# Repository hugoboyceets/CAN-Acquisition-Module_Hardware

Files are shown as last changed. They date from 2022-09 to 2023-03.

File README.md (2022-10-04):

# CAN-Acquisition-Module_Hardware

It's a data acquisition module that can communicate to a PC (and to other modules) over CANbus. This allows for cheap & rugged hardware, as well as simplified wiring and long transmission distances.

At it's core is a Nuvoton M483 microcontroller (ARM Cortex-M4F). It has 8 thermistor inputs, 4 multipurpose analog inputs, and room to accomodate CO2 and/or humidity sensors over I2C or UART.

It can be configured & monitored over USB (it enumerates as a COM port adapter), and a basic screen is present to facilitate human identification and debugging.

The repository for the firmware can be found [here](https://github.com/hboyce4/CAN-Acquisition-Module_Firmware).
The repository the the PC server program can be found [here](https://github.com/hugoboyceets/CAN-Acquisition-Module_Server).

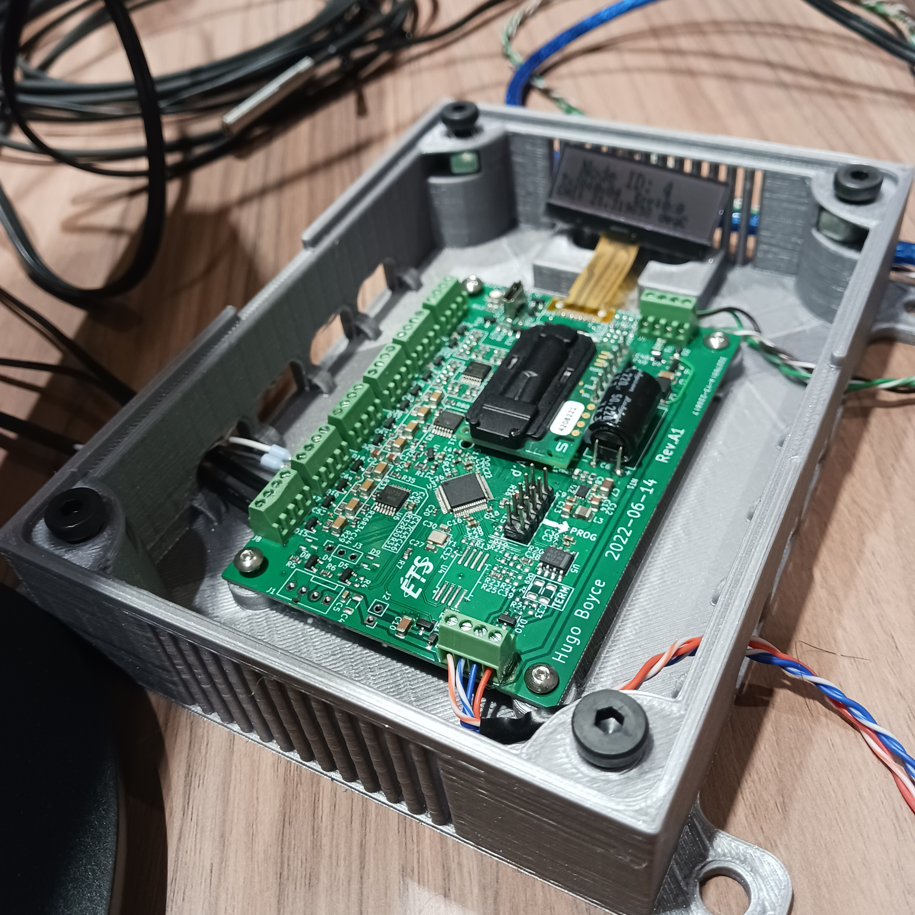
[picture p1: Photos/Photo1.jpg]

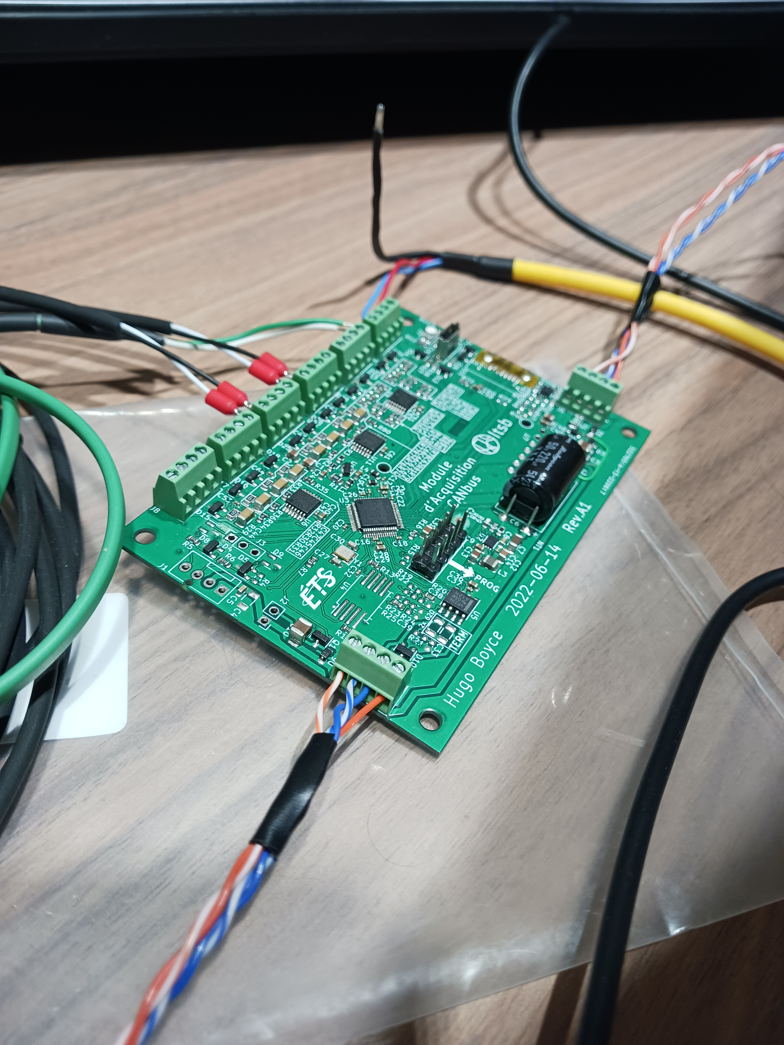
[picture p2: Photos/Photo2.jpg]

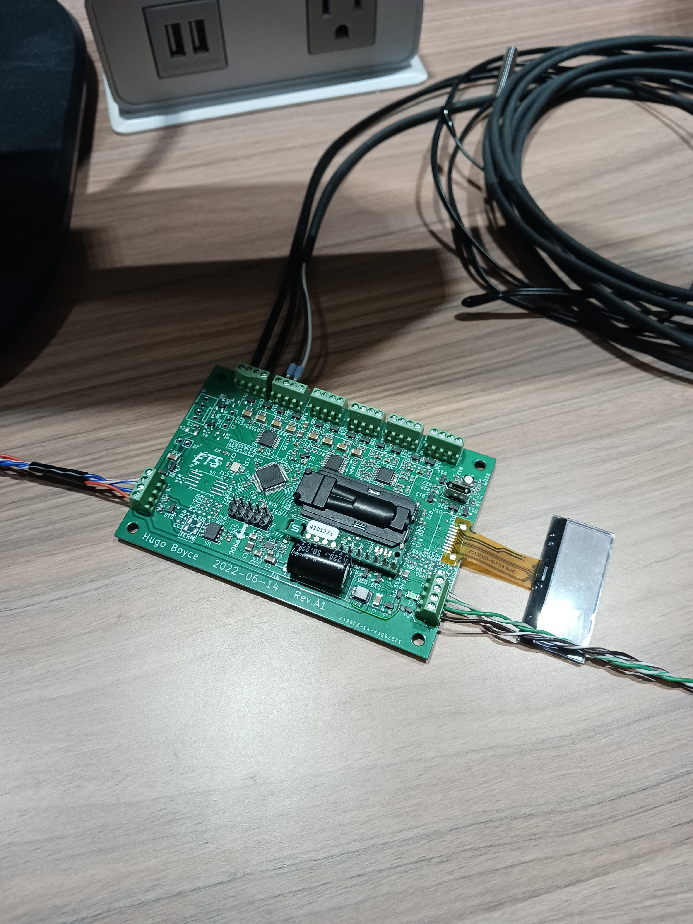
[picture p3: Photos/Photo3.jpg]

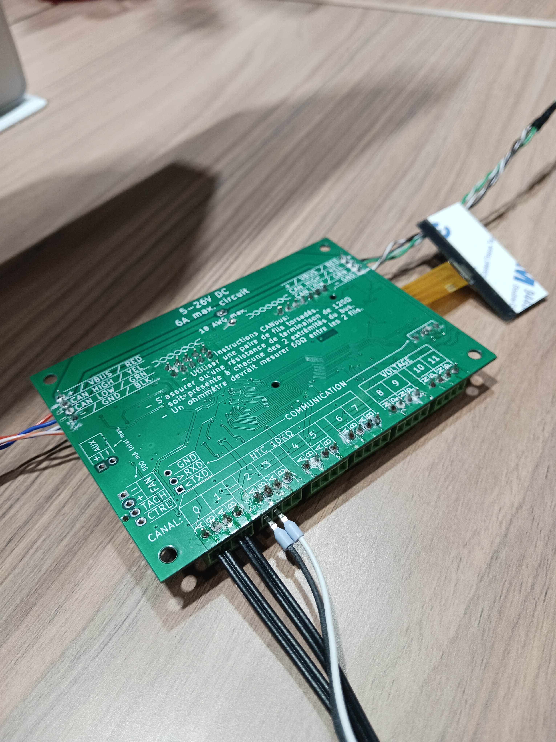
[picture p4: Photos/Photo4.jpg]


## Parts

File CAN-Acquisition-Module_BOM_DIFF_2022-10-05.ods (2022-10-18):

Source: | C:\Users\Hugo Boyce\Documents\Ecole\Maitrise\Projet\PCB\KiCAD\CAN-Acquisition-Module\CAN-Acquisition-Module.kicad_sch
Date: | 2022-10-05 17:15
Tool: | Eeschema (6.0.5)
Generator: | E:\Program Files\KiCad\6.0\bin\scripting\plugins/bom_csv_grouped_by_value_with_fp.py
Component Count: | 210
Ref | Qnty | Stock | Qty needed | Difference | On order | Left | Value | Cmp name | Footprint | Description | Vendor
PCB | 1 | 2
C1, C2, C12, C13, C31, C48, | 6 | 32 | 12 | 20 |  | 20 | 10 uF | C_Small | Capacitor_SMD:C_0805_2012Metric | Unpolarized capacitor, small symbol
C3, C4, C7, C10, C44, C45, C46, C47, C65, C66, C67, C68, | 12 | 1 | 24 | -23 | 25 | 2 | 4.7 uF | C_Small | Capacitor_SMD:C_1206_3216Metric | Unpolarized capacitor, small symbol
C5, C8, | 2 | 44 | 4 | 40 |  | 40 | 100 nF | C_Small | Capacitor_SMD:C_0603_1608Metric | Unpolarized capacitor, small symbol
C6, | 1 | 7 | 2 | 5 |  | 5 | 220 uF | C_Polarized_Small | CAN-Acquisition-Module:CP_Radial_D10.0mm_P5.00mm_Horizontal | Polarized capacitor, small symbol
C9, C15, C19, C23, C24, C29, C36, C40, C49, C51, C55, C56, C57, C58, C59, C61, | 16 | 52 | 32 | 20 |  | 20 | 1 uF | C_Small | Capacitor_SMD:C_0603_1608Metric | Unpolarized capacitor, small symbol
C11, | 1 | 7 | 2 | 5 |  | 5 | 33 pF | C_Small | Capacitor_SMD:C_0603_1608Metric | Unpolarized capacitor, small symbol
C14, C16, C17, C18, C20, C21, C22, C25, C26, C28, C32, C37, C41, C42, C43, C50, C52, C53, C54, C60, C62, C63, C64, | 23 | 33 | 46 | -13 | 50 | 37 | 100 nF | C_Small | Capacitor_SMD:C_0402_1005Metric | Unpolarized capacitor, small symbol
C27, C30, | 2 | 4 | 4 | 0 |  | 0 | 20 pF | C_Small | Capacitor_SMD:C_0603_1608Metric | Unpolarized capacitor, small symbol
C34, C35, | 2 | 4 | 4 | 0 |  | 0 | 47 pF | C_Small | Capacitor_SMD:C_0603_1608Metric | Unpolarized capacitor, small symbol
D1, D2, D6, | 3 | 1 | 6 | -5 | 7 | 2 | CUS05S40 | D | CAN-Acquisition-Module:Toshiba_USC | Diode
D3, D10, | 2 | 4 | 4 | 0 |  | 0 | PESD2CAN | NUP2105L | Package_TO_SOT_SMD:SOT-23 | Dual Line CAN Bus Protector, 24Vrwm
D4, D5, D8, D9, D11, D12, D13, D14, D15, D16, D17, D18, D19, D20, D21, D22, D23, D24, D25, D26, D27, D28, | 22 | 40 | 44 | -4 | 4 | 0 | CM1213A-01SO | CM1213A-01SO | Package_TO_SOT_SMD:SOT-23 | Single Channel ESD Protection Array
D7, | 1 | 1 | 2 | -1 | 2 | 1 | LED_ABRG | LED_ABRG | CAN-Acquisition-Module:LED_RGB_Wuerth-PLCC4_3.2x2.8mm_150141M173100 | RGB LED, anode/blue/red/green
F1, | 1 | 2 | 2 | 0 |  | 0 | 100 mA | Polyfuse_Small | Fuse:Fuse_1206_3216Metric | Resettable fuse, polymeric positive temperature coefficient, small symbol
J4, | 1 | 20 | 2 | 18 |  | 18 | Conn_02x05_Odd_Even | Conn_02x05_Odd_Even | CAN-Acquisition-Module:Nu-Link-Me-v3.0 | Generic connector, double row, 02x05, odd/even pin numbering scheme (row 1 odd numbers, row 2 even numbers), script generated (kicad-library-utils/schlib/autogen/connector/)
J5, J6, J8, J9, J10, J11, J12, J13, | 8 | 1 | 16 | -15 | 15 | 0 | OSTVN04A150 | Screw_Terminal_01x04 | CAN-Acquisition-Module:OSTVN04A150 | Generic screw terminal, single row, 01x04, script generated (kicad-library-utils/schlib/autogen/connector/)
J7, | 1 | 0 | 2 | -2 | 2 | 0 | USB_B_Micro | USB_B_Micro | CAN-Acquisition-Module:GCT-USB3131-30-0230-A | USB Micro Type B connector
L1, L4, L5, L6, | 4 | 88 | 8 | 80 |  | 80 | Ferrite | L_Small | Inductor_SMD:L_0603_1608Metric | Inductor, small symbol
L2, | 1 | 0 | 2 | -2 | 2 | 0 | 470 uH | L_Iron_Small | CAN-Acquisition-Module:Murata_LQH43_1812(4532_Metric) | Inductor with iron core, small symbol
L3, | 1 | 1 | 2 | -1 | 2 | 1 | 4.7 uH | L_Iron_Small | Inductor_SMD:L_1008_2520Metric | Inductor with iron core, small symbol
 |  |  |  |  |  | 0
Q1, | 0 | 1 | 0 | 1 |  | 1 | SI2318A | 2N7002K | Package_TO_SOT_SMD:SOT-23 | 0.38A Id, 60V Vds, N-Channel MOSFET, SOT-23
R1, | 1 | 7 | 2 | 5 |  | 5 | 100R | R_Small_US | Resistor_SMD:R_0805_2012Metric | Resistor, small US symbol
R2, | 1 | 7 | 2 | 5 |  | 5 | 6K8 | R_Small_US | Resistor_SMD:R_0603_1608Metric | Resistor, small US symbol
R3, R9, | 2 | 4 | 4 | 0 |  | 0 | 15K | R_Small_US | Resistor_SMD:R_0603_1608Metric | Resistor, small US symbol
R5, R6, R7, R13, R14, R16, R26, R39, R52, R53, R54, R55, R72, | 13 | 65 | 26 | 39 |  | 39 | 10K | R_Small_US | Resistor_SMD:R_0603_1608Metric | Resistor, small US symbol
R8, R68, R69, R70, R71, | 5 | 86 | 10 | 76 |  | 76 | 47K | R_Small_US | Resistor_SMD:R_0603_1608Metric | Resistor, small US symbol
R10, | 1 | 7 | 2 | 5 |  | 5 | 300R | R_Small_US | Resistor_SMD:R_0603_1608Metric | Resistor, small US symbol
R11, | 1 | 0 | 2 | -2 | 10 | 8 | 220R | R_Small_US | Resistor_SMD:R_0603_1608Metric | Resistor, small US symbol
R12, | 1 | 6 | 2 | 4 |  | 4 | 120R | R_Small_US | Resistor_SMD:R_0603_1608Metric | Resistor, small US symbol
R20, | 1 | 7 | 2 | 5 |  | 5 | 22K | R_Small_US | Resistor_SMD:R_0603_1608Metric | Resistor, small US symbol
R25, R50, R51, R60, R61, R62, R63, | 7 | 79 | 14 | 65 |  | 65 | 1K | R_Small_US | Resistor_SMD:R_0603_1608Metric | Resistor, small US symbol
R27, R28, | 2 | 4 | 4 | 0 |  | 0 | 27R | R_Small_US | Resistor_SMD:R_0603_1608Metric | Resistor, small US symbol
R29, R30, R31, R32, R74, R75, R76, R77, | 8 | 75 | 16 | 59 |  | 59 | 6K2 | R_Small_US | Resistor_SMD:R_0805_2012Metric | Resistor, small US symbol
R33, R34, R35, R36, R78, R79, R80, R81, | 8 | 76 | 16 | 60 |  | 60 | 100R | R_Small_US | Resistor_SMD:R_0603_1608Metric | Resistor, small US symbol
R38, R43, | 2 | 89 | 4 | 85 |  | 85 | 0R | R_Small_US | Resistor_SMD:R_0603_1608Metric | Resistor, small US symbol
R64, R65, R66, R67, | 4 | 0 | 8 | -8 | 10 | 2 | 2K | R_Small_US | Resistor_SMD:R_0603_1608Metric | Resistor, small US symbol
U1, | 1 | 1 | 2 | -1 | 2 | 1 | AZ431LAN | TL431DBZ | Package_TO_SOT_SMD:SOT-23 | Shunt Regulator, SOT-23
U2, | 1 | 7 | 2 | 5 |  | 5 | S-8581AA | S-8581AA | CAN-Acquisition-Module:Ablic_HSTN-8-A | 36 V INPUT, 600 mA SYNCHRONOUS STEP-DOWN SWITCHING REGULATOR
U3, | 1 | 2 | 2 | 0 |  | 0 | M483SGCAE | M483SGCAE2A-CAN-Acquisition-Module | Package_QFP:LQFP-64_7x7mm_P0.4mm
U5, | 1 | 2 | 2 | 0 |  | 0 | SN65HVD234 | SN65HVD234 | Package_SO:SOIC-8_3.9x4.9mm_P1.27mm | CAN Bus Transceiver, 3.3V, 1Mbps, Enable feature, SOIC-8
U6, U11, | 2 | 4 | 4 | 0 |  | 0 | BD12734FVJ-E2 | OPA4196xPW | Package_SO:TSSOP-14_4.4x5mm_P0.65mm | Quad, Low-Power, Low Offset Voltage, Rail-to-Rail Operational Amplifier, TSSOP-14
U7, | 1 | 0 | 2 | -2 | 1 | 0 | SCD30 | SCD30 | CAN-Acquisition-Module:SCD30 | Sensirion IR-based CO2, humidity, and temperature sensor
U8, | 1 | 0 | 2 | -2 | 2 | 0 | SHT35-DIS | SHT35-DIS | CAN-Acquisition-Module:Sensirion_DFN-8-1EP_2.5x2.5mm_P0.5mm_EP1.1x1.7mm | IÃ‚Â²C humidity and temperature sensor, Ã‚Â±1.5%RH, Ã‚Â±0.1Ã‚Â°C, DFN-8
U9, | 1 | 0 | 2 | -2 | 2 | 0 | OPA4317IPWR | OPA4196xPW | Package_SO:TSSOP-14_4.4x5mm_P0.65mm | Quad, Low-Power, Low Offset Voltage, Rail-to-Rail Operational Amplifier, TSSOP-14
U10, | 1 | 0 | 2 | -2 |  | -2 | ERC13232FN-1 | ERC13232FN-1 | CAN-Acquisition-Module:ERC13232FN-1 | EastRising COG Serial 4-line SPI 132x32 Graphic LCD Display No Backlight ST7567A controller
Y1, | 1 | 1 | 2 | -1 | 2 | 1 | 12 MHz | Crystal_GND24_Small | Crystal:Crystal_SMD_3225-4Pin_3.2x2.5mm | Four pin crystal, GND on pins 2 and 4, small symbol

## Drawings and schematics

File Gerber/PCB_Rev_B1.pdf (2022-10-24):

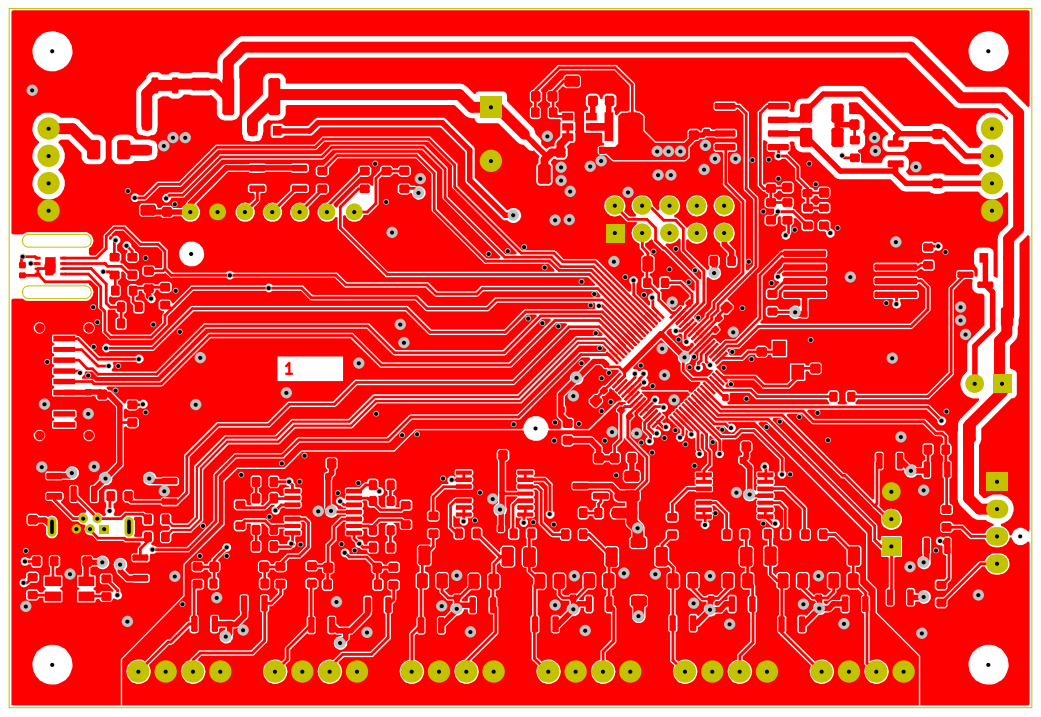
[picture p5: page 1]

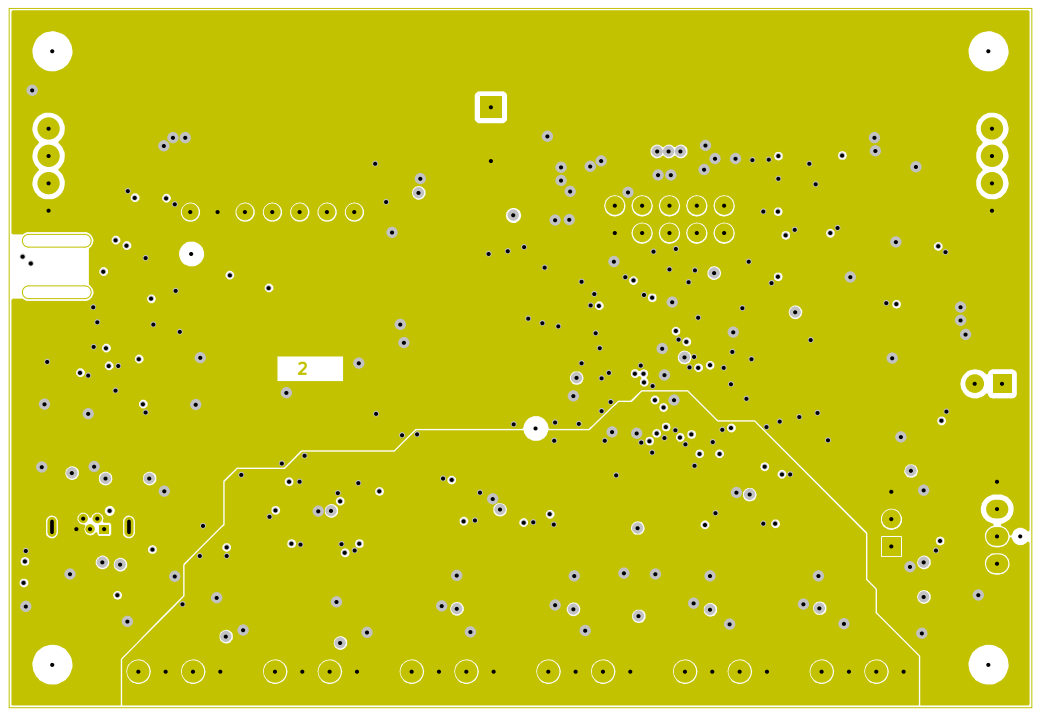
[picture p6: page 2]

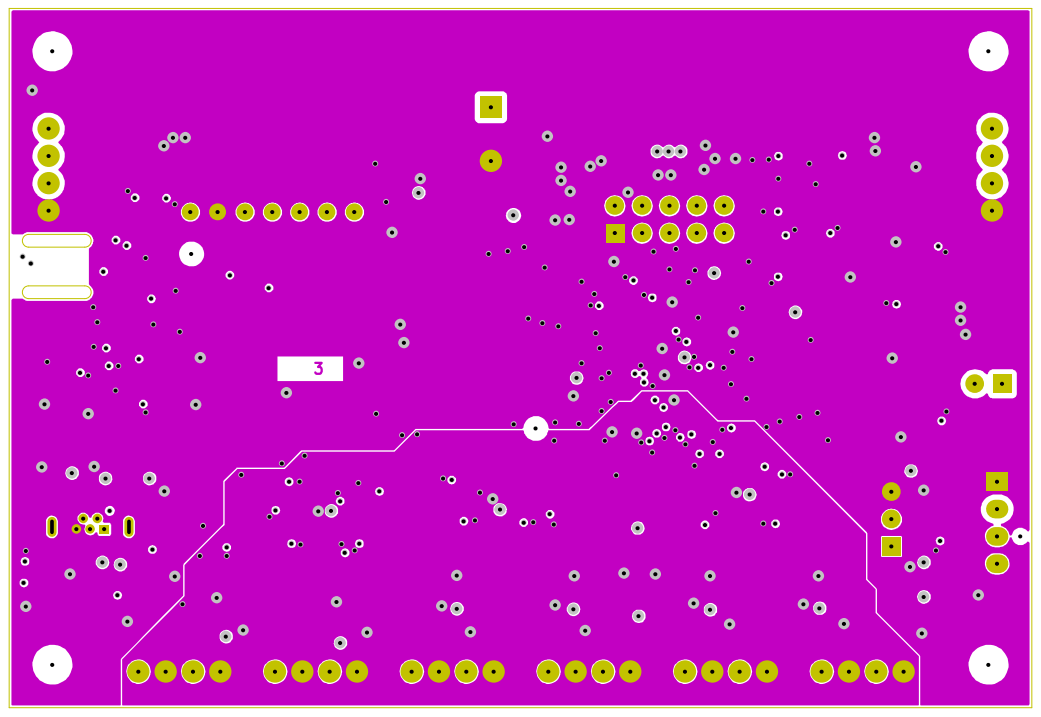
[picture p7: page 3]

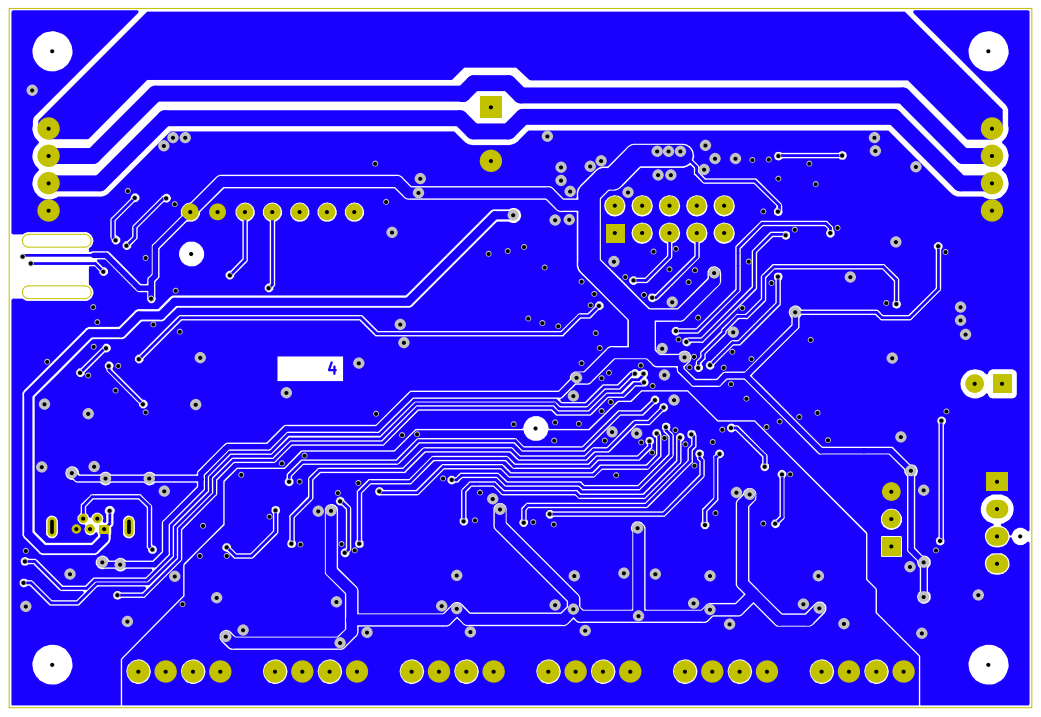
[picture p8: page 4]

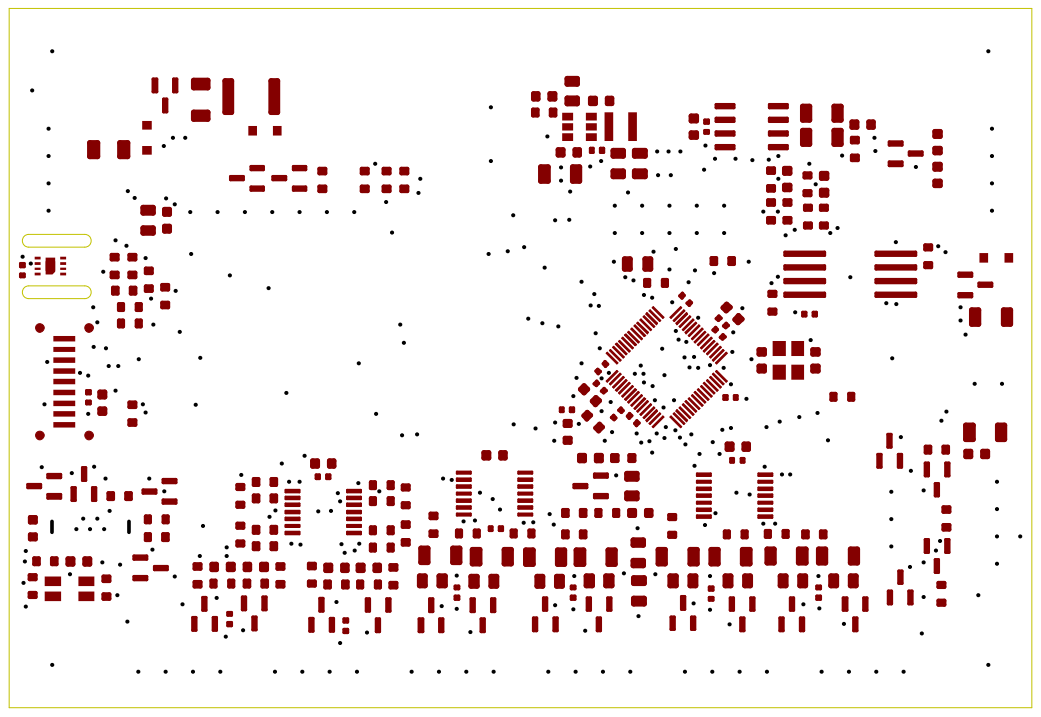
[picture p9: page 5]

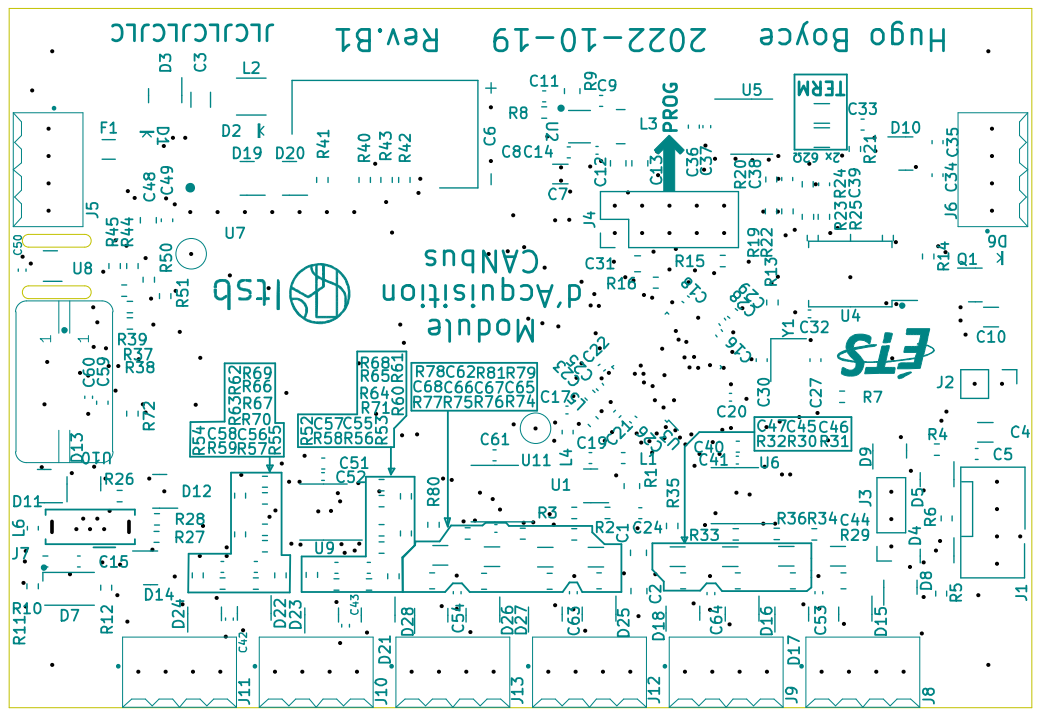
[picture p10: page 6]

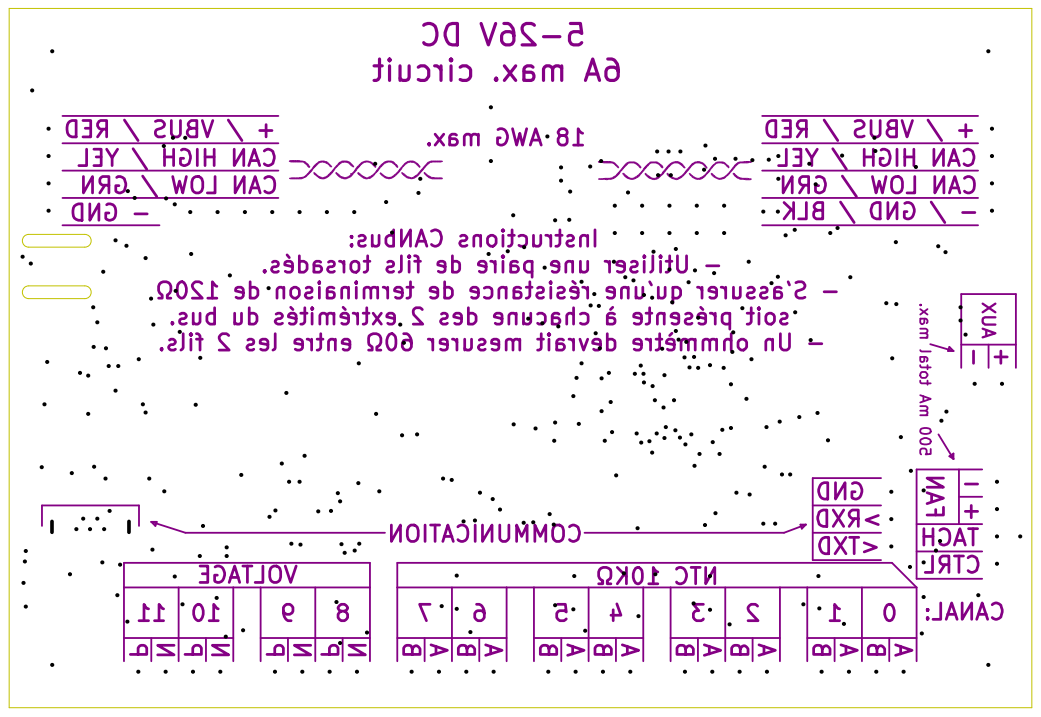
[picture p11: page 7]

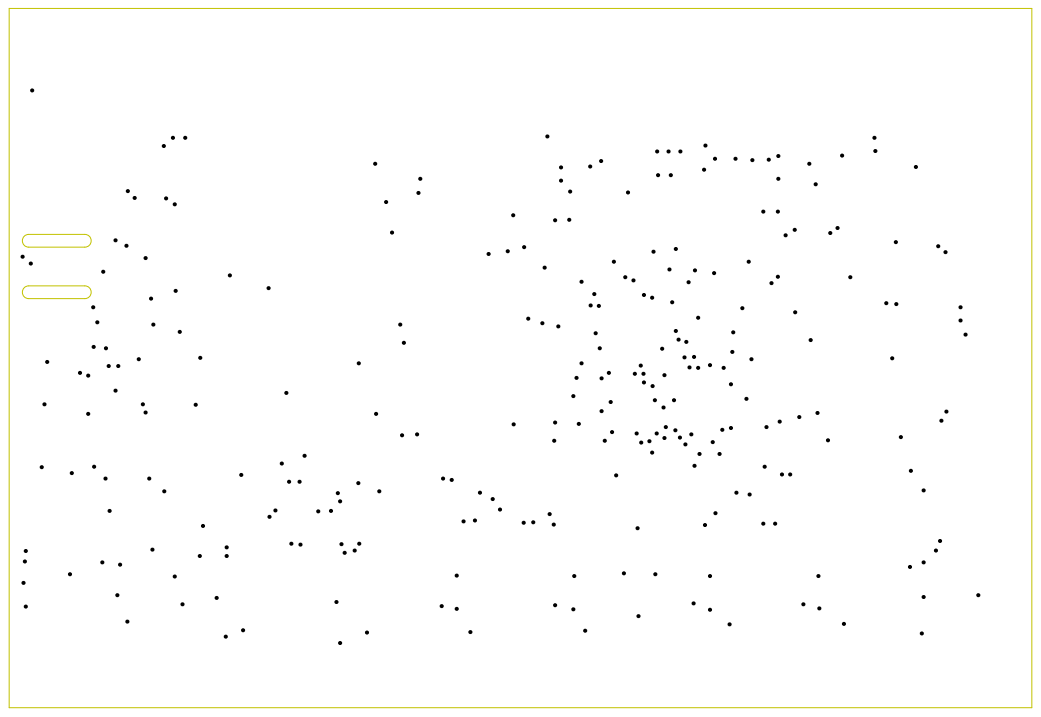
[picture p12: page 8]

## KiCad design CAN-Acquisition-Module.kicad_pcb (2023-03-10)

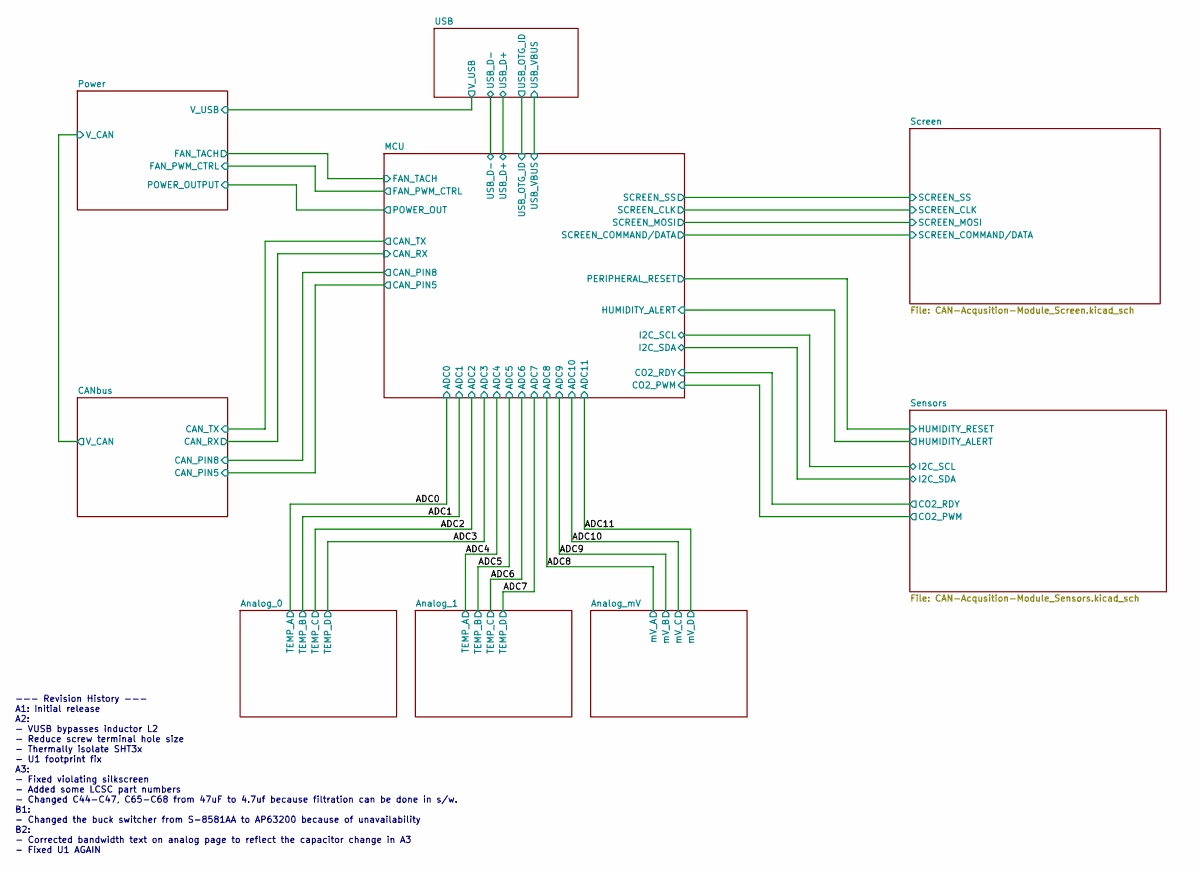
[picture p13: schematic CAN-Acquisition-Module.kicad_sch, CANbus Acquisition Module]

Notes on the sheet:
--- Revision History --- A1: Initial release A2: - VUSB bypasses inductor L2 - Reduce screw terminal hole size - Thermally isolate SHT3x - U1 footprint fix A3: - Fixed violating silkscreen - Added some LCSC part numbers - Changed C44-C47, C65-C68 from 47uF to 4.7uf because filtration can be done in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

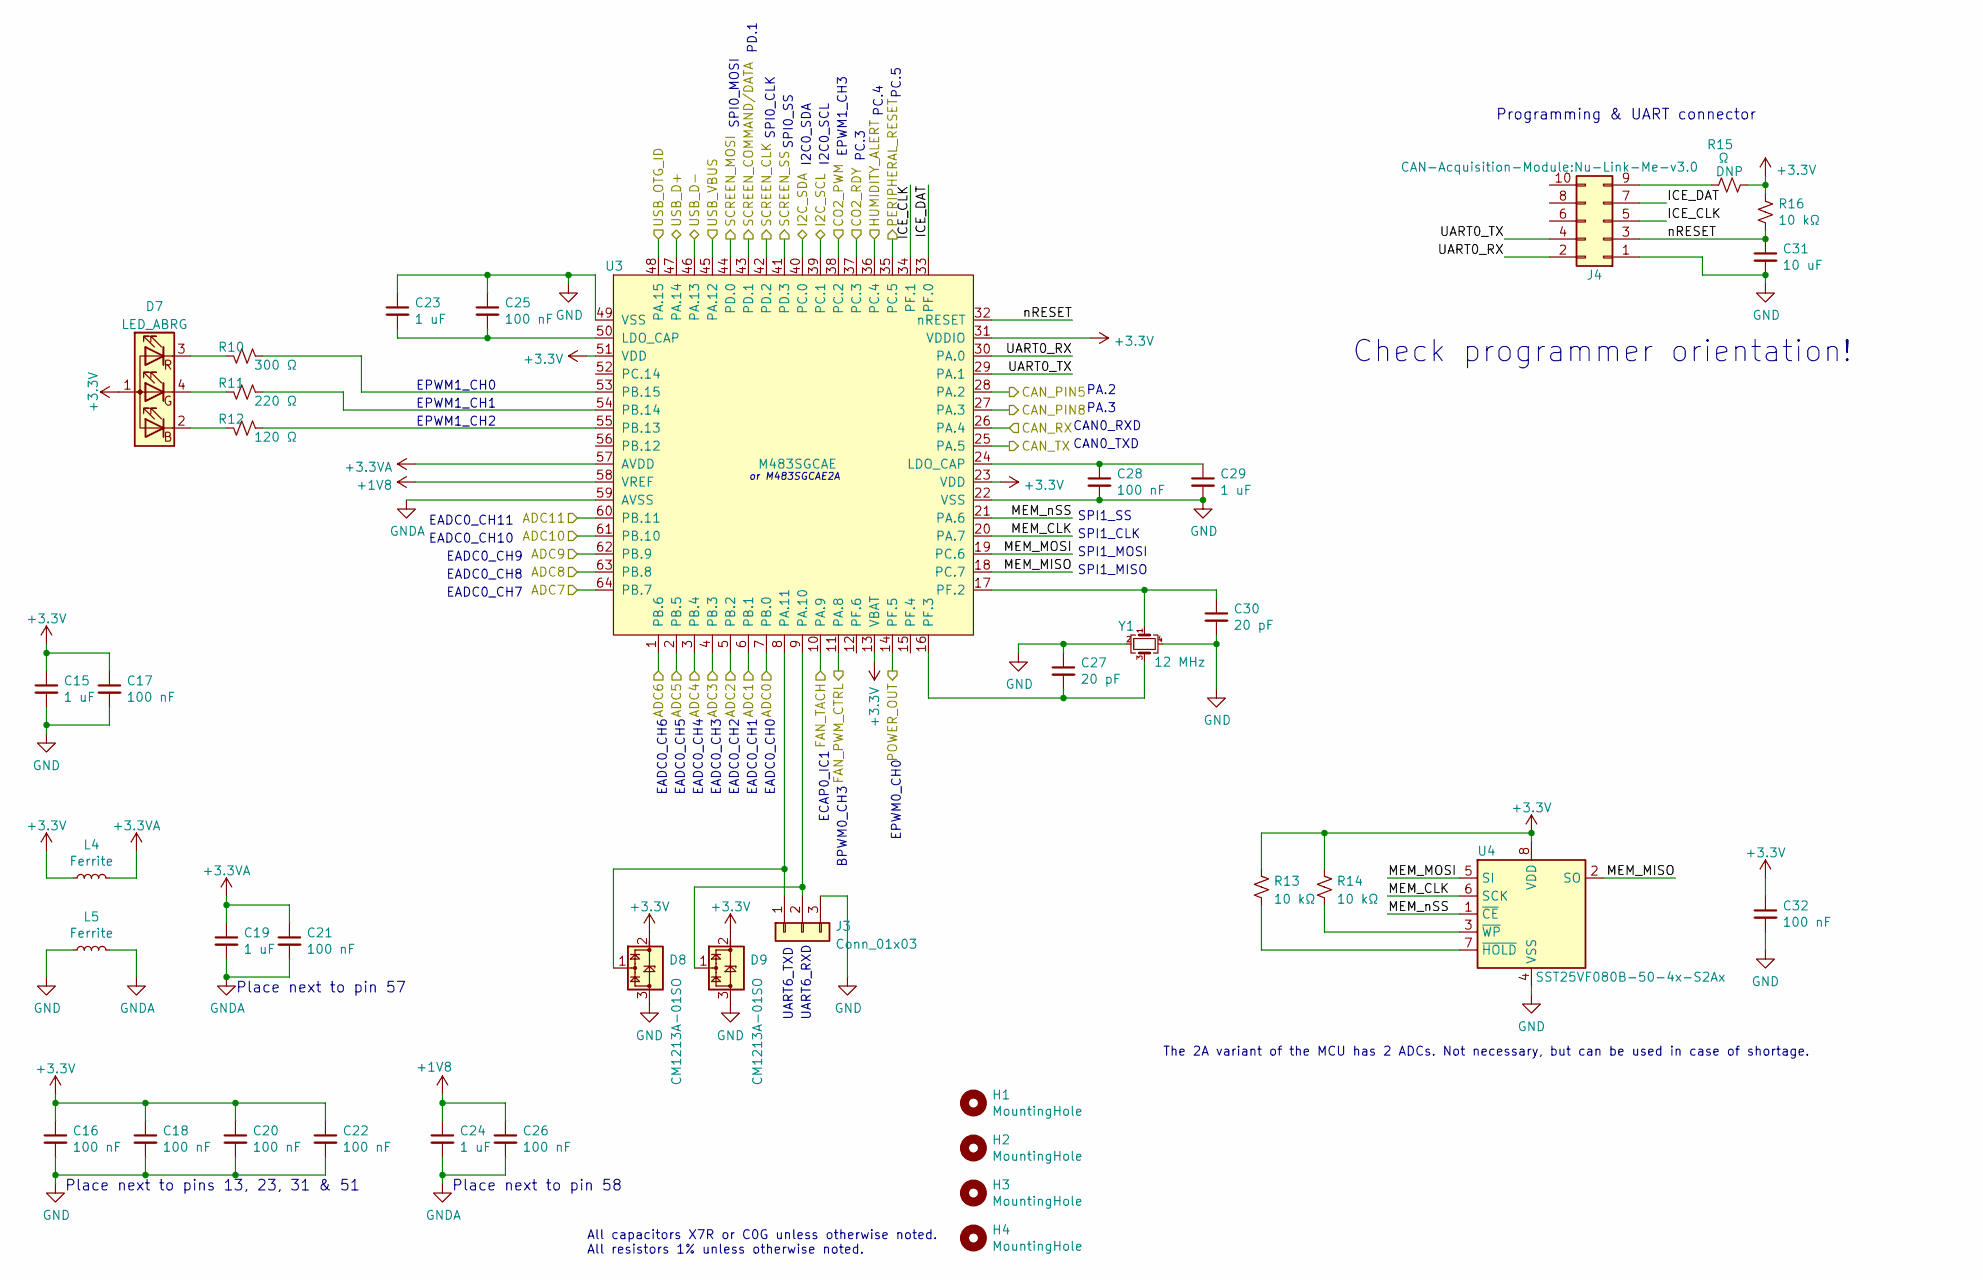
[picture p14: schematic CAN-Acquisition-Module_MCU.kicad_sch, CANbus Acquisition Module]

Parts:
C15, C19, C23, C24, C29: 1 uF; C_0603_1608Metric; Rated Voltage 25V; LCSC P/N C386079
C16, C17, C18, C20, C21, C22, C25, C26, C28, C32: 100 nF; C_0402_1005Metric; Rated Voltage 16V; LCSC P/N C77014
C27, C30: 20 pF; C_0603_1608Metric; LCSC P/N C123543
C31: 10 uF; C_0805_2012Metric; Rated Voltage 6.3V; LCSC P/N C386019
D7: LED_ABRG; LED_RGB_Wuerth-PLCC4_3.2x2.8mm_150141M173100; LCSC P/N C409779
D8, D9: CM1213A-01SO; SOT-23; LCSC P/N C558429
H1, H2, H3, H4: MountingHole; MountingHole_3.2mm_M3; LCSC P/N DNP
J3: Conn_01x03; PinSocket_1x03_P2.54mm_Vertical; LCSC P/N DNP
J4: Conn_02x05_Odd_Even; Nu-Link-Me-v3.0; LCSC P/N C124387
L4, L5: Ferrite; L_0603_1608Metric; LCSC P/N C96995
R10: 300 Ω; R_0603_1608Metric; Tolerance 1%; LCSC P/N C114617
R11: 220 Ω; R_0603_1608Metric; Tolerance 1%; LCSC P/N C22962
R12: 120 Ω; R_0603_1608Metric; Tolerance 1%; LCSC P/N C22787
R13, R14, R16: 10 kΩ; R_0603_1608Metric; Tolerance 1%; LCSC P/N C98220
R15: Ω; R_0603_1608Metric; LCSC P/N DNP
U3: M483SGCAE; LQFP-64_7x7mm_P0.4mm; LCSC P/N C3231235
U4: SST25VF080B-50-4x-S2Ax; SOIC-8_P1.27mm_Multi; LCSC P/N DNP
Y1: 12 MHz; Crystal_SMD_3225-4Pin_3.2x2.5mm; LCSC P/N C91749

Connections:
+1V8: C24.1, C26.1, U3.58 (VREF); also elsewhere on the board
+3.3VA: C19.1, C21.1, L4.2, U3.57 (AVDD); also elsewhere on the board
+3V3: C15.1, C16.1, C17.1, C18.1, C20.1, C22.1, C32.1, D7.1 (A), D8.2 (VP), D9.2 (VP), L4.1, R13.1, R14.1, R15.2, R16.1, U3.13 (VBAT), U3.23 (VDD), U3.31 (VDDIO), U3.51 (VDD), U4.8 (VDD); also elsewhere on the board
/ADC0: U3.7 (PB.0); also elsewhere on the board
/ADC1: U3.6 (PB.1); also elsewhere on the board
/ADC2: U3.5 (PB.2); also elsewhere on the board
/ADC3: U3.4 (PB.3); also elsewhere on the board
/ADC4: U3.3 (PB.4); also elsewhere on the board
/ADC5: U3.2 (PB.5); also elsewhere on the board
/ADC6: U3.1 (PB.6); also elsewhere on the board
/ADC7: U3.64 (PB.7); also elsewhere on the board
/ADC8: U3.63 (PB.8); also elsewhere on the board
/ADC9: U3.62 (PB.9); also elsewhere on the board
/ADC10: U3.61 (PB.10); also elsewhere on the board
/ADC11: U3.60 (PB.11); also elsewhere on the board
/CANbus/CAN_PIN5: U3.28 (PA.2); also elsewhere on the board
/CANbus/CAN_PIN8: U3.27 (PA.3); also elsewhere on the board
/CANbus/CAN_RX: U3.26 (PA.4); also elsewhere on the board
/CANbus/CAN_TX: U3.25 (PA.5); also elsewhere on the board
/MCU/CO2_PWM: U3.38 (PC.2); also elsewhere on the board
/MCU/CO2_RDY: U3.37 (PC.3); also elsewhere on the board
/MCU/FAN_PWM_CTRL: U3.11 (PA.8); also elsewhere on the board
/MCU/FAN_TACH: U3.10 (PA.9); also elsewhere on the board
/MCU/HUMIDITY_ALERT: U3.36 (PC.4); also elsewhere on the board
/MCU/I2C_SCL: U3.39 (PC.1); also elsewhere on the board
/MCU/I2C_SDA: U3.40 (PC.0); also elsewhere on the board
/MCU/ICE_CLK: J4.5, U3.34 (PF.1)
/MCU/ICE_DAT: J4.7, U3.33 (PF.0)
/MCU/MEM_CLK: U3.20 (PA.7), U4.6 (SCK)
/MCU/MEM_MISO: U3.18 (PC.7), U4.2 (SO)
/MCU/MEM_MOSI: U3.19 (PC.6), U4.5 (SI)
/MCU/MEM_nSS: U3.21 (PA.6), U4.1 (~CE)
/MCU/PERIPHERAL_RESET: U3.35 (PC.5); also elsewhere on the board
/MCU/POWER_OUT: U3.14 (PF.5); also elsewhere on the board
/MCU/SCREEN_CLK: U3.42 (PD.2); also elsewhere on the board
/MCU/SCREEN_COMMAND/DATA: U3.43 (PD.1); also elsewhere on the board
/MCU/SCREEN_MOSI: U3.44 (PD.0); also elsewhere on the board
/MCU/SCREEN_SS: U3.41 (PD.3); also elsewhere on the board
/MCU/UART0_RX: J4.2, U3.30 (PA.0)
/MCU/UART0_TX: J4.4, U3.29 (PA.1)
/MCU/USB_D+: U3.47 (PA.14); also elsewhere on the board
/MCU/USB_D-: U3.46 (PA.13); also elsewhere on the board
/MCU/USB_OTG_ID: U3.48 (PA.15); also elsewhere on the board
/MCU/USB_VBUS: U3.45 (PA.12); also elsewhere on the board
/MCU/nRESET: C31.1, J4.3, R16.2, U3.32 (nRESET)
GND: C15.2, C16.2, C17.2, C18.2, C20.2, C22.2, C23.1, C25.1, C27.1, C28.2, C29.2, C30.2, C31.2, C32.2, D8.3 (VN), D9.3 (VN), J3.3, J4.1, L5.1, U3.22 (VSS), U3.49 (VSS), U4.4 (VSS), Y1.2, Y1.4; also elsewhere on the board
GNDA: C19.2, C21.2, C24.2, C26.2, L5.2, U3.59 (AVSS); also elsewhere on the board
unnamed: C23.2, C25.2, U3.50 (LDO_CAP)
unnamed: C27.2, U3.16 (PF.3), Y1.3
unnamed: C28.1, C29.1, U3.24 (LDO_CAP)
unnamed: C30.1, U3.17 (PF.2), Y1.1
unnamed: D7.2 (BK), R12.2
unnamed: D7.3 (RK), R10.2
unnamed: D7.4 (GK), R11.2
unnamed: D8.1 (CH1), J3.1, U3.8 (PA.11)
unnamed: D9.1 (CH1), J3.2, U3.9 (PA.10)
unnamed: J4.9, R15.1
unnamed: R10.1, U3.53 (PB.15)
unnamed: R11.1, U3.54 (PB.14)
unnamed: R12.1, U3.55 (PB.13)
unnamed: R13.2, U4.7 (~HOLD)
unnamed: R14.2, U4.3 (~WP)

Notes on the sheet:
PD.1
I2C0_SDA
SPI1_CLK
Programming & UART connector
PA.3
EADC0_CH9
EPWM1_CH3
EADC0_CH5
Place next to pins 13, 23, 31 & 51
EADC0_CH10
SPI0_SS
The 2A variant of the MCU has 2 ADCs. Not necessary, but can be used in case of shortage.
EPWM1_CH0
PC.5
PC.3
EADC0_CH6
ECAP0_IC1
CAN0_RXD
CAN0_TXD
Place next to pin 58
SPI0_MOSI
EADC0_CH0
Check programmer orientation!
UART6_RXD
PC.4
EPWM1_CH1
UART6_TXD
All capacitors X7R or C0G unless otherwise noted. All resistors 1% unless otherwise noted.
Place next to pin 57
EPWM0_CH0
SPI1_MISO
EADC0_CH7
or M483SGCAE2A
BPWM0_CH3
EADC0_CH8
EADC0_CH1
EADC0_CH2
EPWM1_CH2
EADC0_CH4
SPI0_CLK

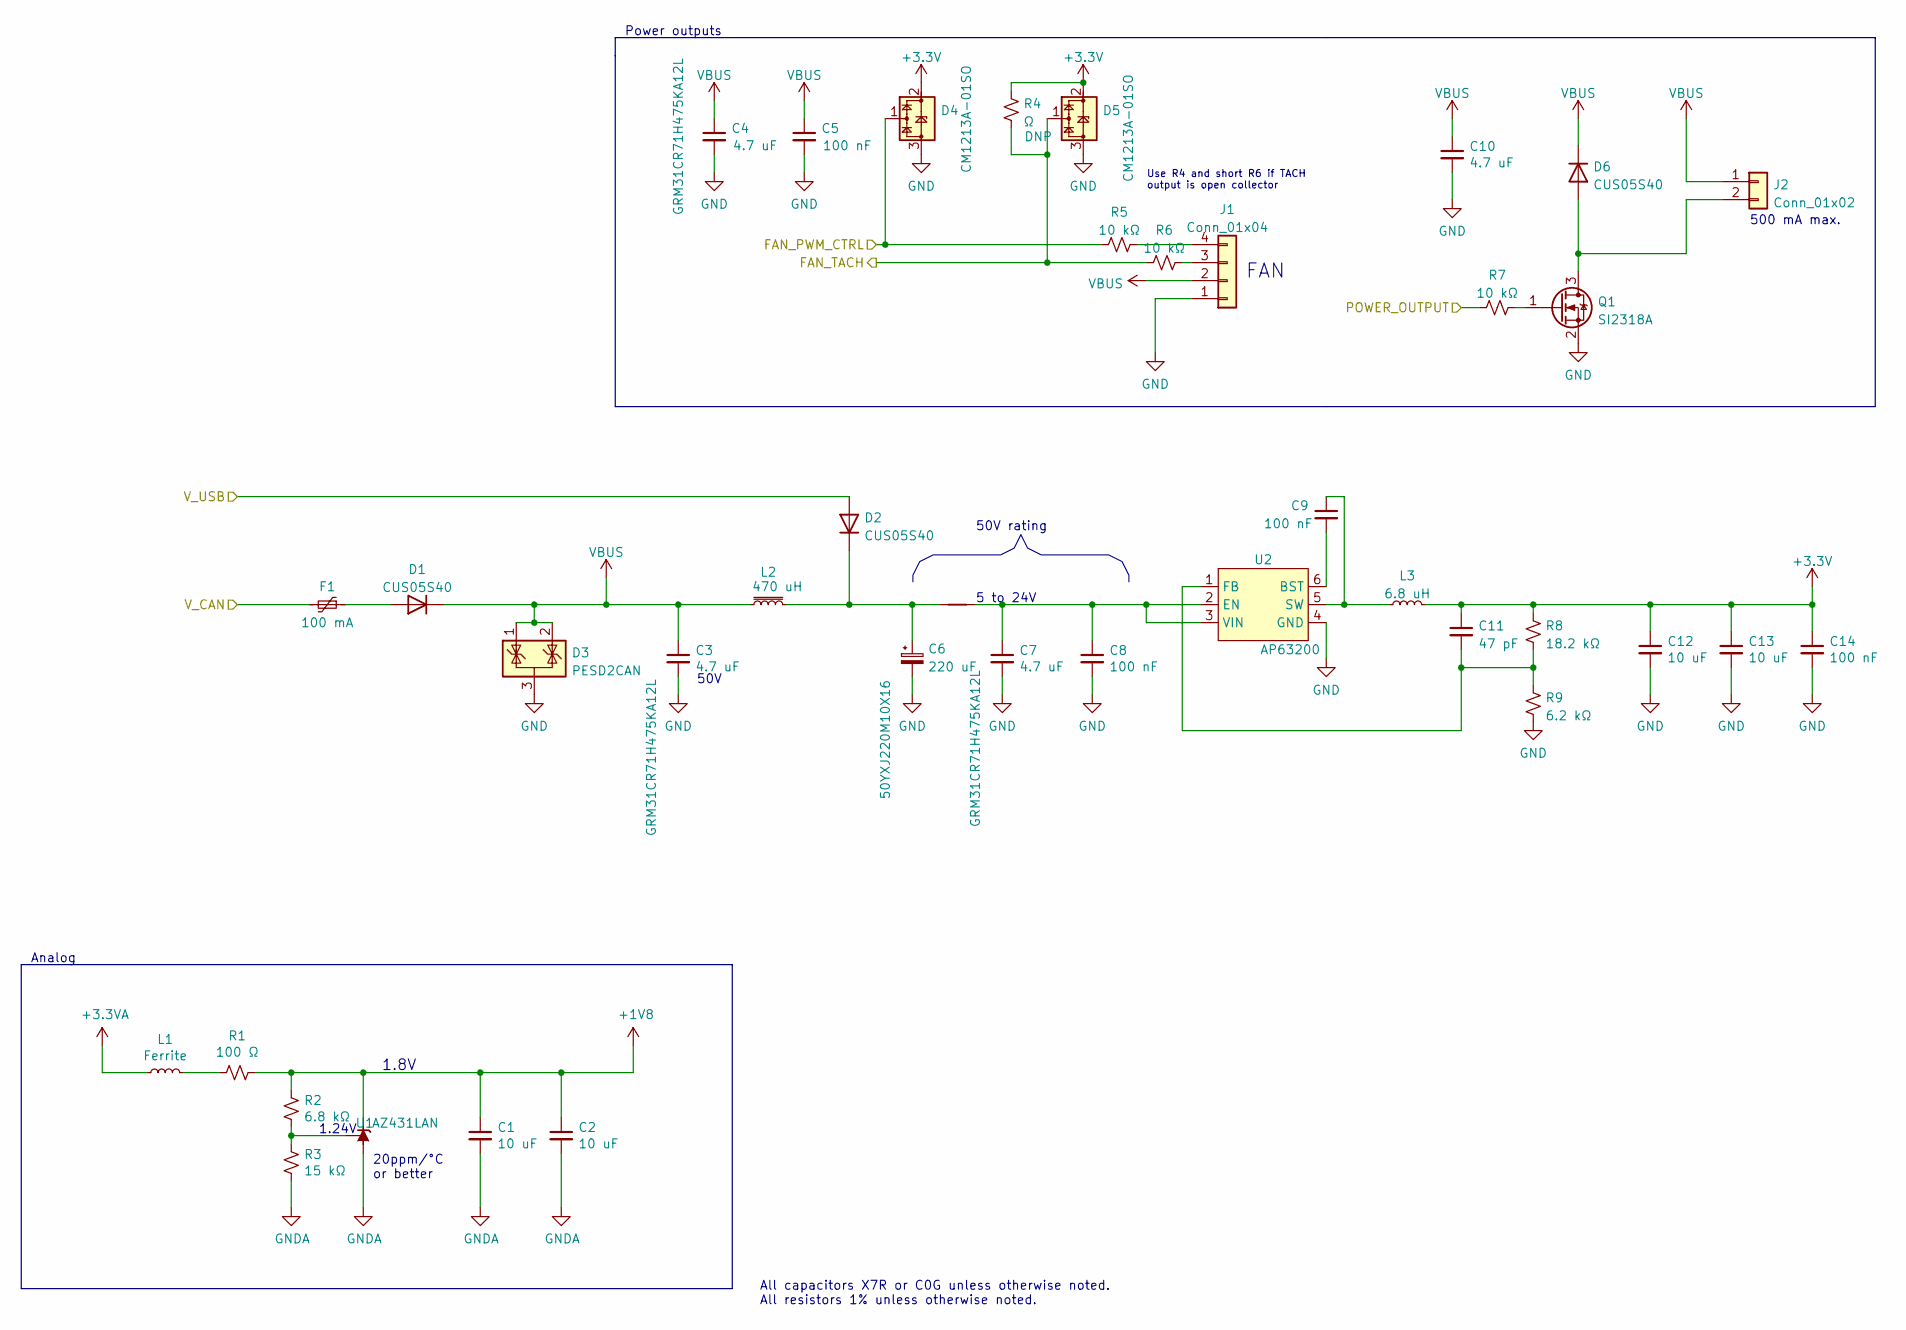
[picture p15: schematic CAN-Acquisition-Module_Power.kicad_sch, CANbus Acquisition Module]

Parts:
C1, C2, C12, C13: 10 uF; C_0805_2012Metric; Rated Voltage 6.3V; LCSC P/N C386019
C3, C4, C7, C10: 4.7 uF; C_1206_3216Metric; Rated Voltage 50V; LCSC P/N C92853
C5, C8, C9: 100 nF; C_0603_1608Metric; Rated Voltage 50V; LCSC P/N C314282
C6: 220 uF; CP_Radial_D10.0mm_P5.00mm_Horizontal; Rated Voltage 50V; LCSC P/N DNP
C11: 47 pF; C_0603_1608Metric; LCSC P/N C126580
C14: 100 nF; C_0402_1005Metric; Rated Voltage 16V; LCSC P/N C77014
D1, D2, D6: CUS05S40; Toshiba_USC; LCSC P/N C2762696
D3: PESD2CAN; SOT-23; LCSC P/N C284078
D4, D5: CM1213A-01SO; SOT-23; LCSC P/N C558429
F1: 100 mA; Fuse_1206_3216Metric; LCSC P/N C70065
J1: Conn_01x04; FanPinHeader_1x04_P2.54mm_Vertical; LCSC P/N DNP
J2: Conn_01x02; PinHeader_1x02_P2.54mm_Vertical; LCSC P/N DNP
L1: Ferrite; L_0603_1608Metric; LCSC P/N C96995
L2: 470 uH; Murata_LQH43_1812(4532_Metric); LCSC P/N C394141
L3: 6.8 uH; Murata_LQH3_1212(3030_Metric); LCSC P/N C703775
NT1: NetTie_2; Net_Tie_small; LCSC P/N DNP
Q1: SI2318A; SOT-23; LCSC P/N DNP
R1: 100 Ω; R_0805_2012Metric; Tolerance 5%; LCSC P/N C17408
R2: 6.8 kΩ; R_0603_1608Metric; Tolerance 0.1%; LCSC P/N C55912
R3: 15 kΩ; R_0603_1608Metric; Tolerance 0.1%; LCSC P/N C60590
R4: Ω; R_0603_1608Metric; LCSC P/N DNP
R5, R6, R7: 10 kΩ; R_0603_1608Metric; Tolerance 1%; LCSC P/N C98220
R8: 18.2 kΩ; R_0603_1608Metric; Tolerance 1%; LCSC P/N C22892
R9: 6.2 kΩ; R_0805_2012Metric; Tolerance 0.1%; LCSC P/N C351551
U1: AZ431LAN; SOT-23; LCSC P/N C460576
U2: AP63200; Diodes-Inc_TSOT26; LCSC P/N C2071868

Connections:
+1V8: C1.1, C2.1, R1.1, R2.1, U1.2 (K); also elsewhere on the board
+3.3VA: L1.1; also elsewhere on the board
+3V3: C11.1, C12.1, C13.1, C14.1, D4.2 (VP), D5.2 (VP), L3.2, R4.2, R8.1; also elsewhere on the board
/CANbus/V+/RED: F1.2; also elsewhere on the board
/MCU/FAN_PWM_CTRL: D4.1 (CH1), R5.1; also elsewhere on the board
/MCU/FAN_TACH: D5.1 (CH1), R4.1, R6.1; also elsewhere on the board
/MCU/POWER_OUT: R7.1; also elsewhere on the board
/Power/V_USB: D2.2 (A); also elsewhere on the board
GND: C3.2, C4.2, C5.2, C6.2, C7.2, C8.2, C10.2, C12.2, C13.2, C14.2, D3.3 (A), D4.3 (VN), D5.3 (VN), J1.1, Q1.2 (S), R9.2, U2.4 (GND); also elsewhere on the board
GNDA: C1.2, C2.2, R3.2, U1.3 (A); also elsewhere on the board
unnamed: C6.1, D2.1 (K), L2.2, NT1.1
unnamed: C7.1, C8.1, NT1.2, U2.2 (EN), U2.3 (VIN)
unnamed: C9.1, L3.1, U2.5 (SW)
unnamed: C9.2, U2.6 (BST)
unnamed: C11.2, R8.2, R9.1, U2.1 (FB)
unnamed: D1.2 (A), F1.1
unnamed: D6.2 (A), J2.2, Q1.3 (D)
unnamed: J1.3, R6.2
unnamed: J1.4, R5.2
unnamed: L1.2, R1.2
unnamed: Q1.1 (G), R7.2
unnamed: R2.2, R3.1, U1.1 (REF)
VBUS: C3.1, C4.1, C5.1, C10.1, D1.1 (K), D3.1 (K), D3.2 (K), D6.1 (K), J1.2, J2.1, L2.1

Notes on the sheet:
50V
5 to 24V
1.8V
FAN
Power outputs
Analog
All capacitors X7R or C0G unless otherwise noted. All resistors 1% unless otherwise noted.
Use R4 and short R6 if TACH output is open collector
1.24V
50V rating
500 mA max.
20ppm/°C or better

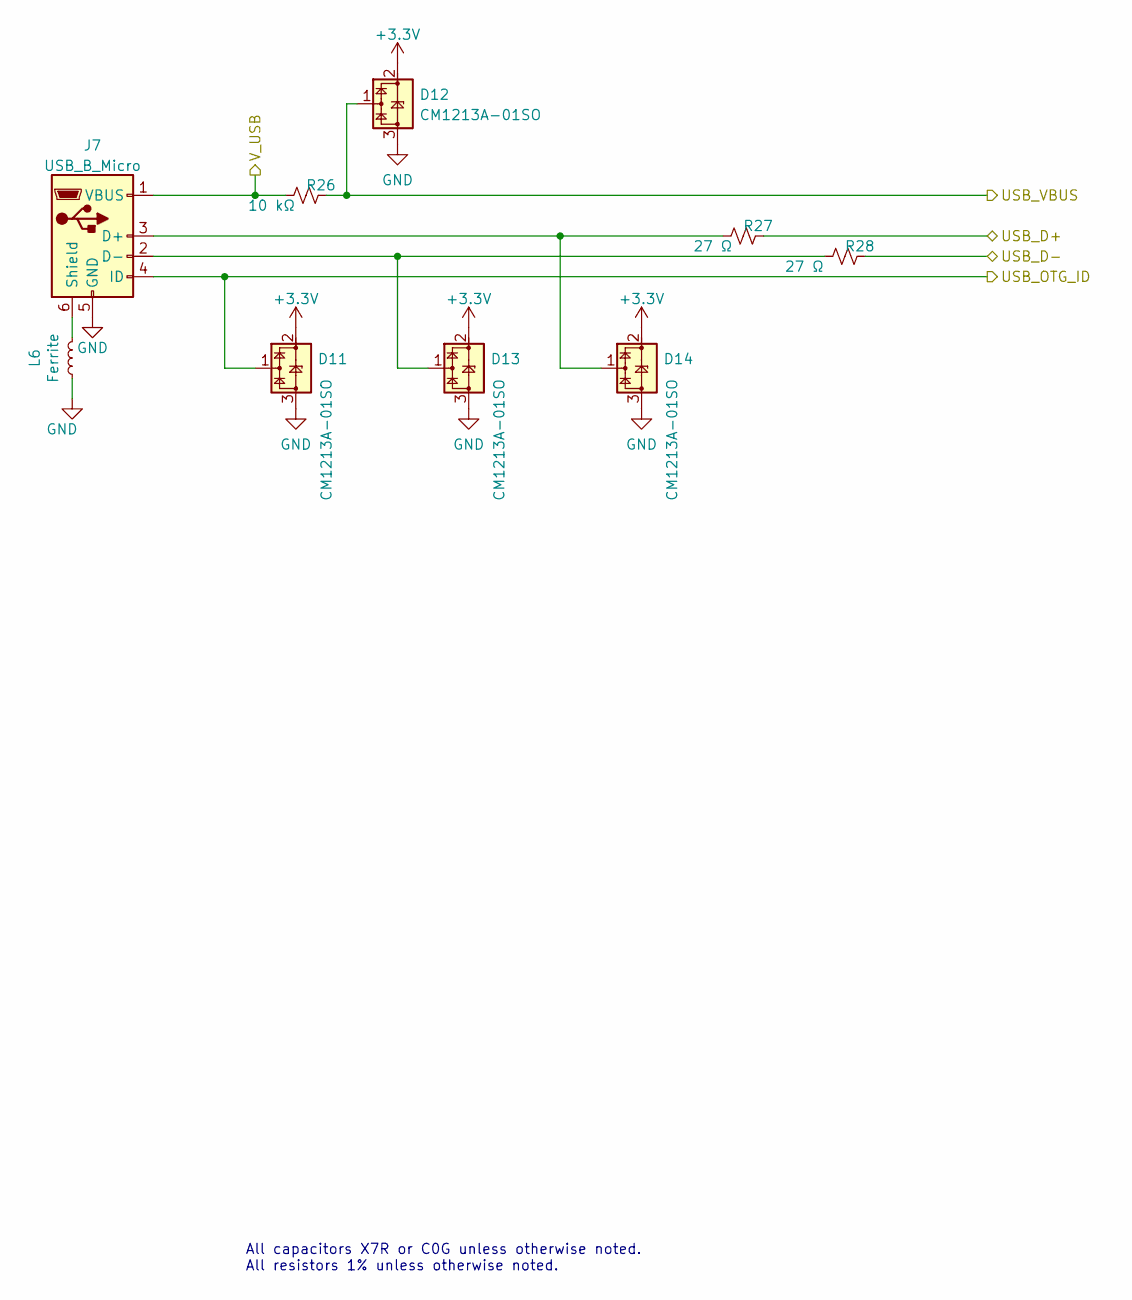
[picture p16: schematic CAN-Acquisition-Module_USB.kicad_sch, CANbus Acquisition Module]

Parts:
D11, D12, D13, D14: CM1213A-01SO; SOT-23; LCSC P/N C558429
J7: USB_B_Micro; GCT-USB3131-30-0230-A; LCSC P/N C920231
L6: Ferrite; L_0603_1608Metric; LCSC P/N C96995
R26: 10 kΩ; R_0603_1608Metric; Tolerance 1%; LCSC P/N C98220
R27, R28: 27 Ω; R_0603_1608Metric; Tolerance 1%; LCSC P/N C25190

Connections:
+3V3: D11.2 (VP), D12.2 (VP), D13.2 (VP), D14.2 (VP); also elsewhere on the board
/MCU/USB_D+: R27.2; also elsewhere on the board
/MCU/USB_D-: R28.2; also elsewhere on the board
/MCU/USB_OTG_ID: D11.1 (CH1), J7.4 (ID); also elsewhere on the board
/MCU/USB_VBUS: D12.1 (CH1), R26.2; also elsewhere on the board
/Power/V_USB: J7.1 (VBUS), R26.1; also elsewhere on the board
GND: D11.3 (VN), D12.3 (VN), D13.3 (VN), D14.3 (VN), J7.5 (GND), L6.1; also elsewhere on the board
unnamed: D13.1 (CH1), J7.2 (D-), R28.1
unnamed: D14.1 (CH1), J7.3 (D+), R27.1
unnamed: J7.6 (Shield), L6.2

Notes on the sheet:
All capacitors X7R or C0G unless otherwise noted. All resistors 1% unless otherwise noted.

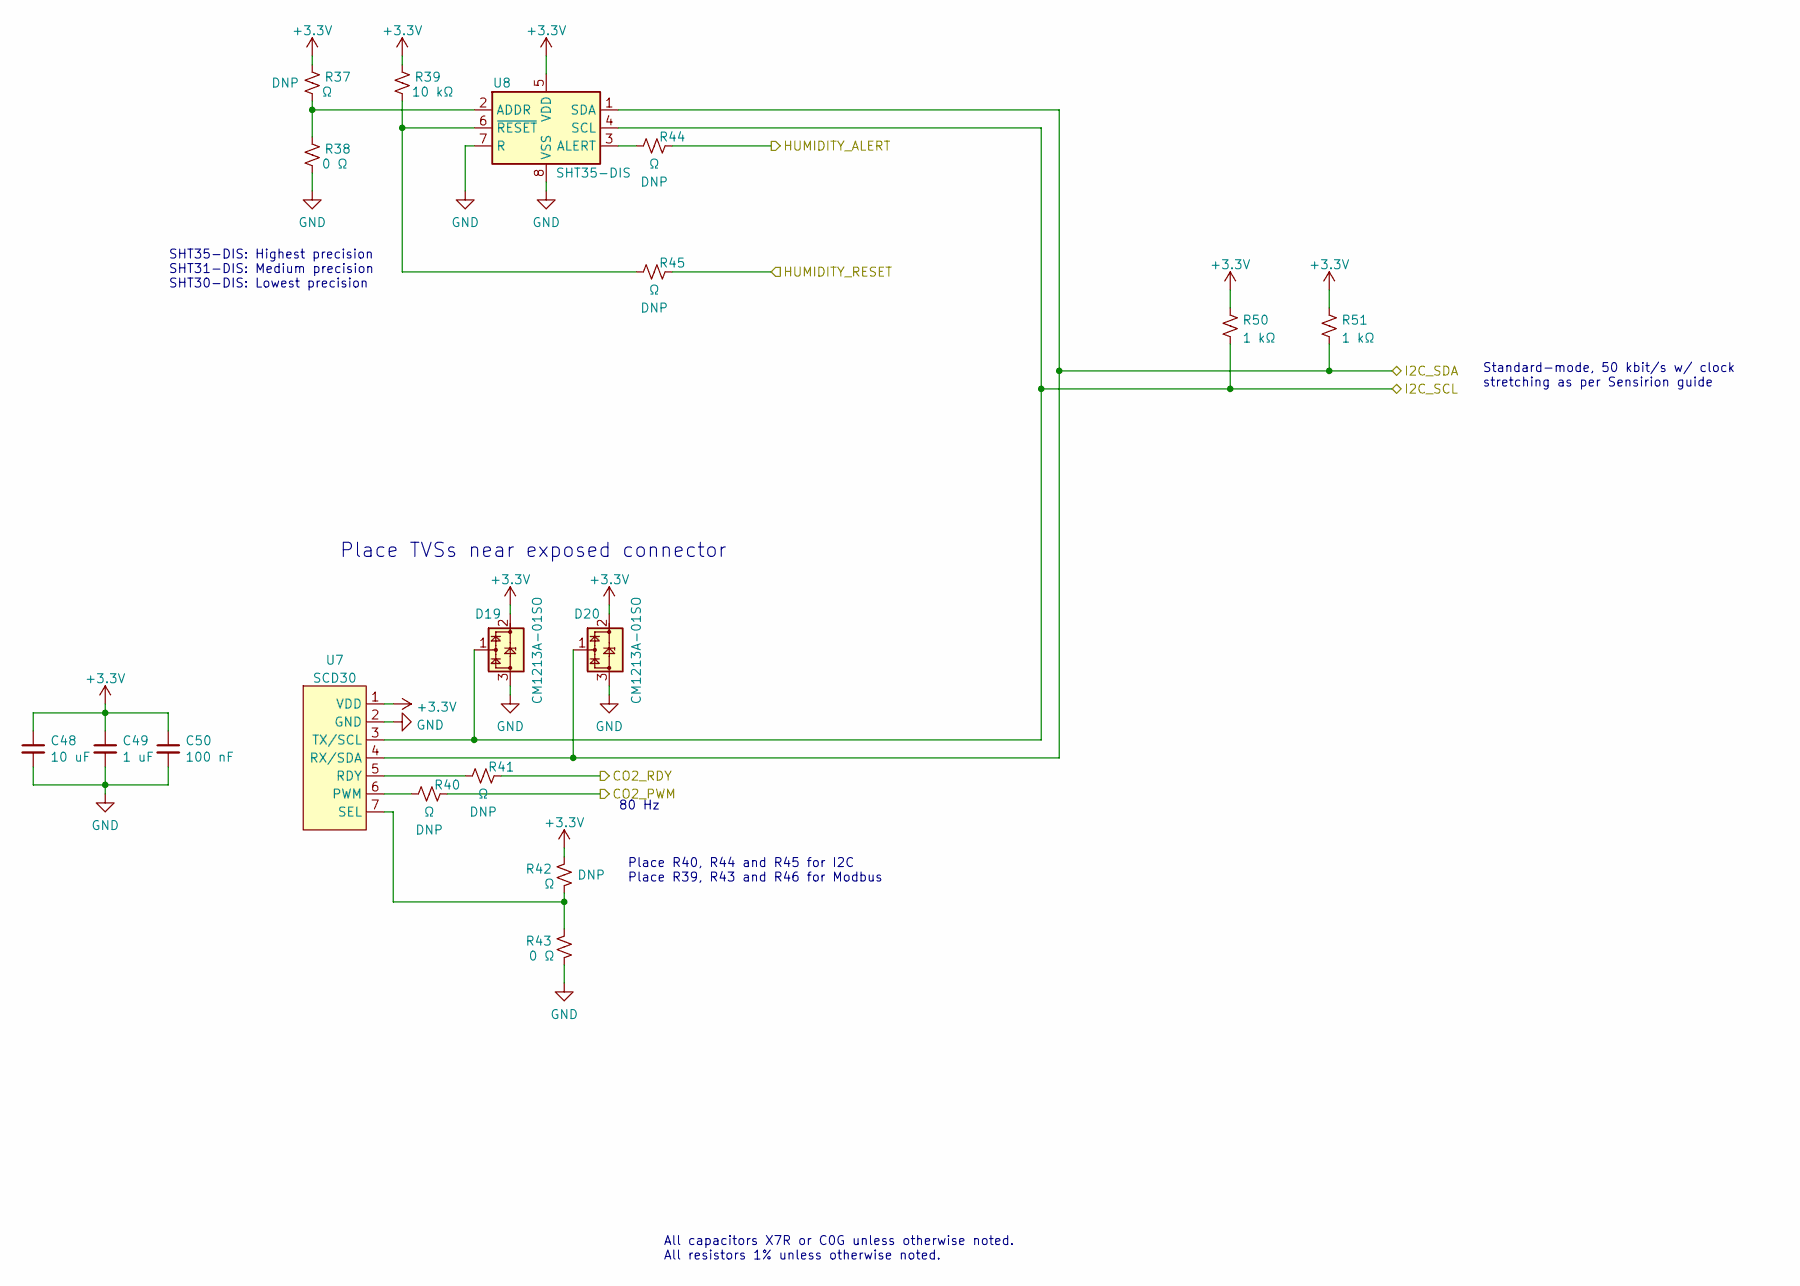
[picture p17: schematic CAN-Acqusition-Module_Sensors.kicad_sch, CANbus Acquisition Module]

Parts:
C48: 10 uF; C_0805_2012Metric; Rated Voltage 6.3V; LCSC P/N C386019
C49: 1 uF; C_0603_1608Metric; Rated Voltage 25V; LCSC P/N C386079
C50: 100 nF; C_0402_1005Metric; Rated Voltage 16V; LCSC P/N C77014
D19, D20: CM1213A-01SO; SOT-23; LCSC P/N C558429
R37, R40, R41, R42, R44, R45: Ω; R_0603_1608Metric; LCSC P/N DNP
R38, R43: 0 Ω; R_0603_1608Metric; Tolerance 1%; LCSC P/N C21189
R39: 10 kΩ; R_0603_1608Metric; Tolerance 1%; LCSC P/N C98220
R50, R51: 1 kΩ; R_0603_1608Metric; Tolerance 1%; LCSC P/N C22548
U7: SCD30; LCSC P/N DNP
U8: SHT35-DIS; Sensirion_DFN-8-1EP_2.5x2.5mm_P0.5mm_EP1.1x1.7mm; LCSC P/N DNP

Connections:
+3V3: C48.1, C49.1, C50.1, D19.2 (VP), D20.2 (VP), R37.1, R39.1, R42.1, R50.1, R51.1, U7.1 (VDD), U8.5 (VDD); also elsewhere on the board
/MCU/CO2_PWM: R40.2; also elsewhere on the board
/MCU/CO2_RDY: R41.2; also elsewhere on the board
/MCU/HUMIDITY_ALERT: R44.2; also elsewhere on the board
/MCU/I2C_SCL: D19.1 (CH1), R50.2, U7.3 (TX/SCL), U8.4 (SCL); also elsewhere on the board
/MCU/I2C_SDA: D20.1 (CH1), R51.2, U7.4 (RX/SDA), U8.1 (SDA); also elsewhere on the board
/MCU/PERIPHERAL_RESET: R45.2; also elsewhere on the board
GND: C48.2, C49.2, C50.2, D19.3 (VN), D20.3 (VN), R38.2, R43.2, U7.2 (GND), U8.7 (R), U8.8 (VSS), U8.9 (VSS); also elsewhere on the board
unnamed: R37.2, R38.1, U8.2 (ADDR)
unnamed: R39.2, R45.1, U8.6 (~RESET)
unnamed: R40.1, U7.6 (PWM)
unnamed: R41.1, U7.5 (RDY)
unnamed: R42.2, R43.1, U7.7 (SEL)
unnamed: R44.1, U8.3 (ALERT)

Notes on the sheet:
80 Hz
SHT35-DIS: Highest precision SHT31-DIS: Medium precision SHT30-DIS: Lowest precision
All capacitors X7R or C0G unless otherwise noted. All resistors 1% unless otherwise noted.
Place R40, R44 and R45 for I2C Place R39, R43 and R46 for Modbus
Standard-mode, 50 kbit/s w/ clock stretching as per Sensirion guide
Place TVSs near exposed connector

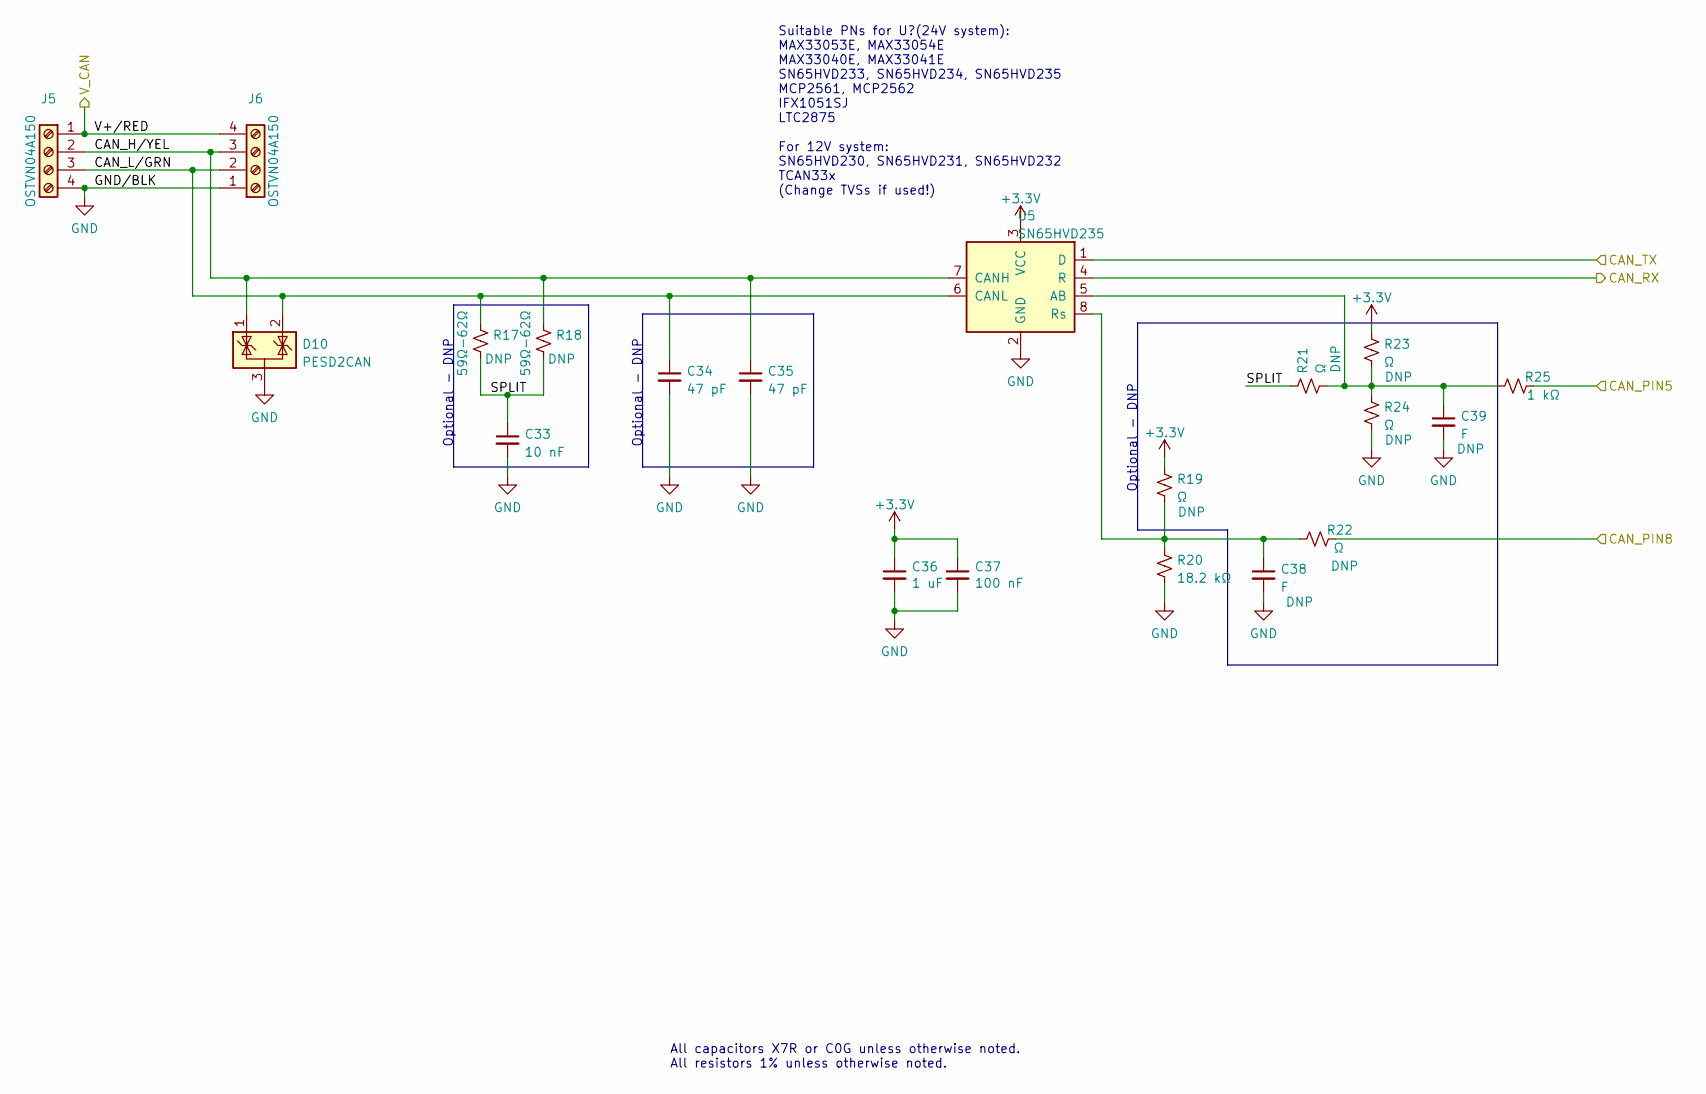
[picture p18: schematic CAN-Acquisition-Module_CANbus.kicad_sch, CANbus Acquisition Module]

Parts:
C33: 10 nF; C_0603_1608Metric; LCSC P/N DNP
C34, C35: 47 pF; C_0603_1608Metric; LCSC P/N C126580
C36: 1 uF; C_0603_1608Metric; Rated Voltage 25V; LCSC P/N C386079
C37: 100 nF; C_0402_1005Metric; Rated Voltage 16V; LCSC P/N C77014
C38, C39: F; C_0603_1608Metric; LCSC P/N DNP
D10: PESD2CAN; SOT-23; LCSC P/N C284078
J5, J6: OSTVN04A150; LCSC P/N C708735
R17, R18: 59Ω-62Ω; R_1206_3216Metric; LCSC P/N DNP
R19, R21, R22, R23, R24: Ω; R_0603_1608Metric; LCSC P/N DNP
R20: 18.2 kΩ; R_0603_1608Metric; Tolerance 1%; LCSC P/N C22892
R25: 1 kΩ; R_0603_1608Metric; Tolerance 1%; LCSC P/N C22548
U5: SN65HVD235; SOIC-8_3.9x4.9mm_P1.27mm; LCSC P/N C111810

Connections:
+3V3: C36.1, C37.1, R19.1, R23.1, U5.3 (VCC); also elsewhere on the board
/CANbus/CAN_H/YEL: C35.1, D10.1 (K), J5.2, J6.3, R18.1, U5.7 (CANH)
/CANbus/CAN_L/GRN: C34.1, D10.2 (K), J5.3, J6.2, R17.1, U5.6 (CANL)
/CANbus/CAN_PIN5: R25.2; also elsewhere on the board
/CANbus/CAN_PIN8: R22.2; also elsewhere on the board
/CANbus/CAN_RX: U5.4 (R); also elsewhere on the board
/CANbus/CAN_TX: U5.1 (D); also elsewhere on the board
/CANbus/SPLIT: C33.1, R17.2, R18.2, R21.1
/CANbus/V+/RED: J5.1, J6.4; also elsewhere on the board
GND: C33.2, C34.2, C35.2, C36.2, C37.2, C38.2, C39.2, D10.3 (A), J5.4, J6.1, R20.2, R24.2, U5.2 (GND); also elsewhere on the board
unnamed: C38.1, R19.2, R20.1, R22.1, U5.8 (Rs)
unnamed: C39.1, R21.2, R23.2, R24.1, R25.1, U5.5 (AB)

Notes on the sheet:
All capacitors X7R or C0G unless otherwise noted. All resistors 1% unless otherwise noted.
Optional - DNP
Suitable PNs for U?(24V system): MAX33053E, MAX33054E MAX33040E, MAX33041E SN65HVD233, SN65HVD234, SN65HVD235 MCP2561, MCP2562 IFX1051SJ LTC2875 For 12V system: SN65HVD230, SN65HVD231, SN65HVD232 TCAN33x (Change TVSs if used!)

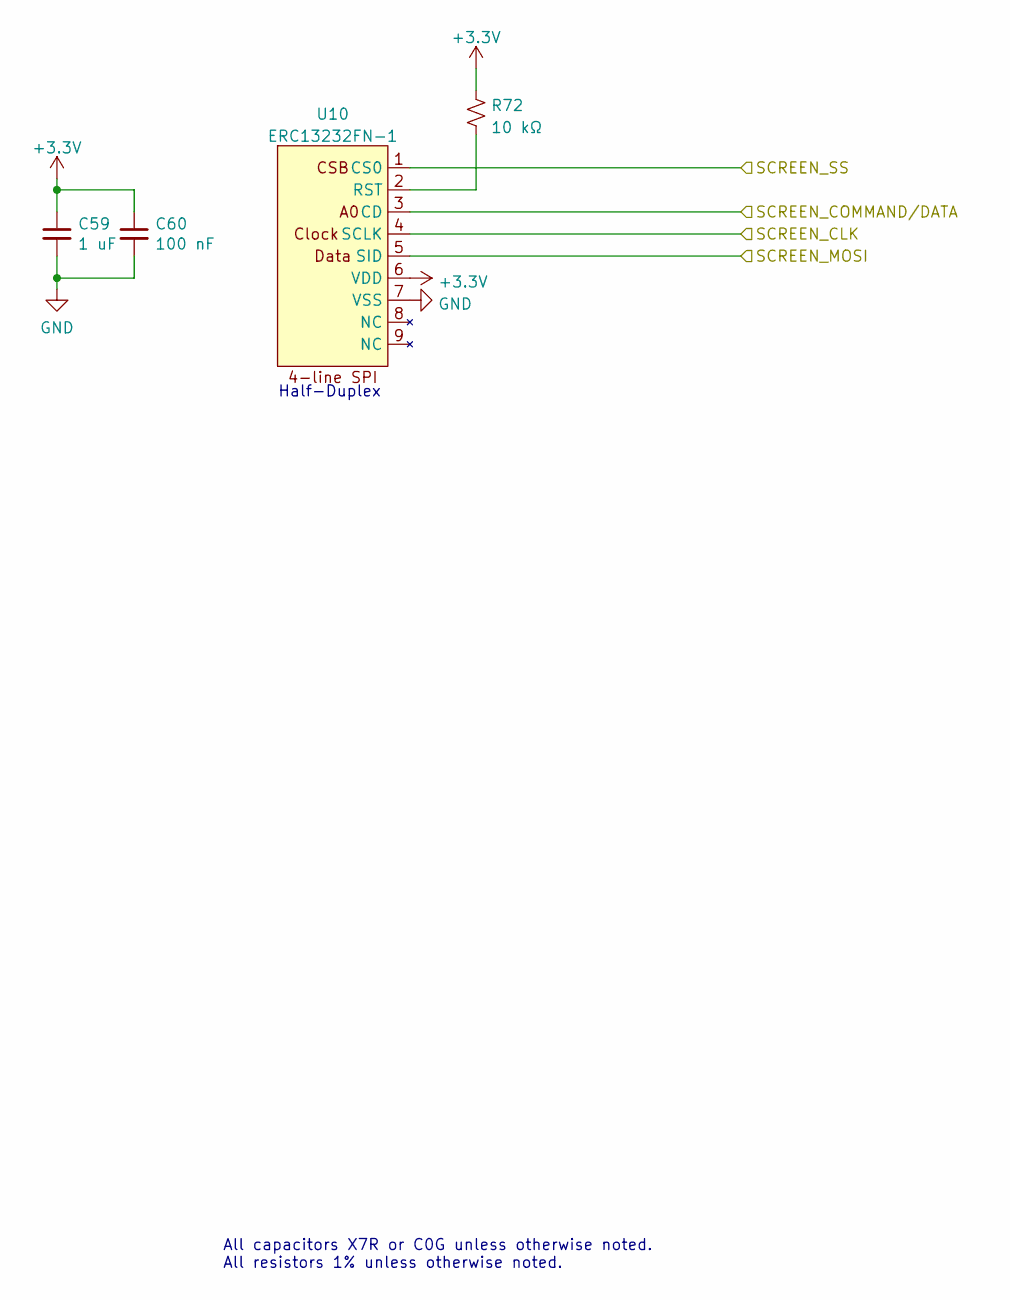
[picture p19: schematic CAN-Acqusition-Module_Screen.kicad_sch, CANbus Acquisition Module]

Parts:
C59: 1 uF; C_0603_1608Metric; Rated Voltage 25V; LCSC P/N C386079
C60: 100 nF; C_0402_1005Metric; Rated Voltage 16V; LCSC P/N C77014
R72: 10 kΩ; R_0603_1608Metric; Tolerance 1%; LCSC P/N C98220
U10: ERC13232FN-1; LCSC P/N DNP

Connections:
+3V3: C59.1, C60.1, R72.1, U10.6 (VDD); also elsewhere on the board
/MCU/SCREEN_CLK: U10.4 (SCLK); also elsewhere on the board
/MCU/SCREEN_COMMAND/DATA: U10.3 (CD); also elsewhere on the board
/MCU/SCREEN_MOSI: U10.5 (SID); also elsewhere on the board
/MCU/SCREEN_SS: U10.1 (CS0); also elsewhere on the board
GND: C59.2, C60.2, U10.7 (VSS); also elsewhere on the board
unnamed: R72.2, U10.2 (RST)

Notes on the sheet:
Half-Duplex
All capacitors X7R or C0G unless otherwise noted. All resistors 1% unless otherwise noted.

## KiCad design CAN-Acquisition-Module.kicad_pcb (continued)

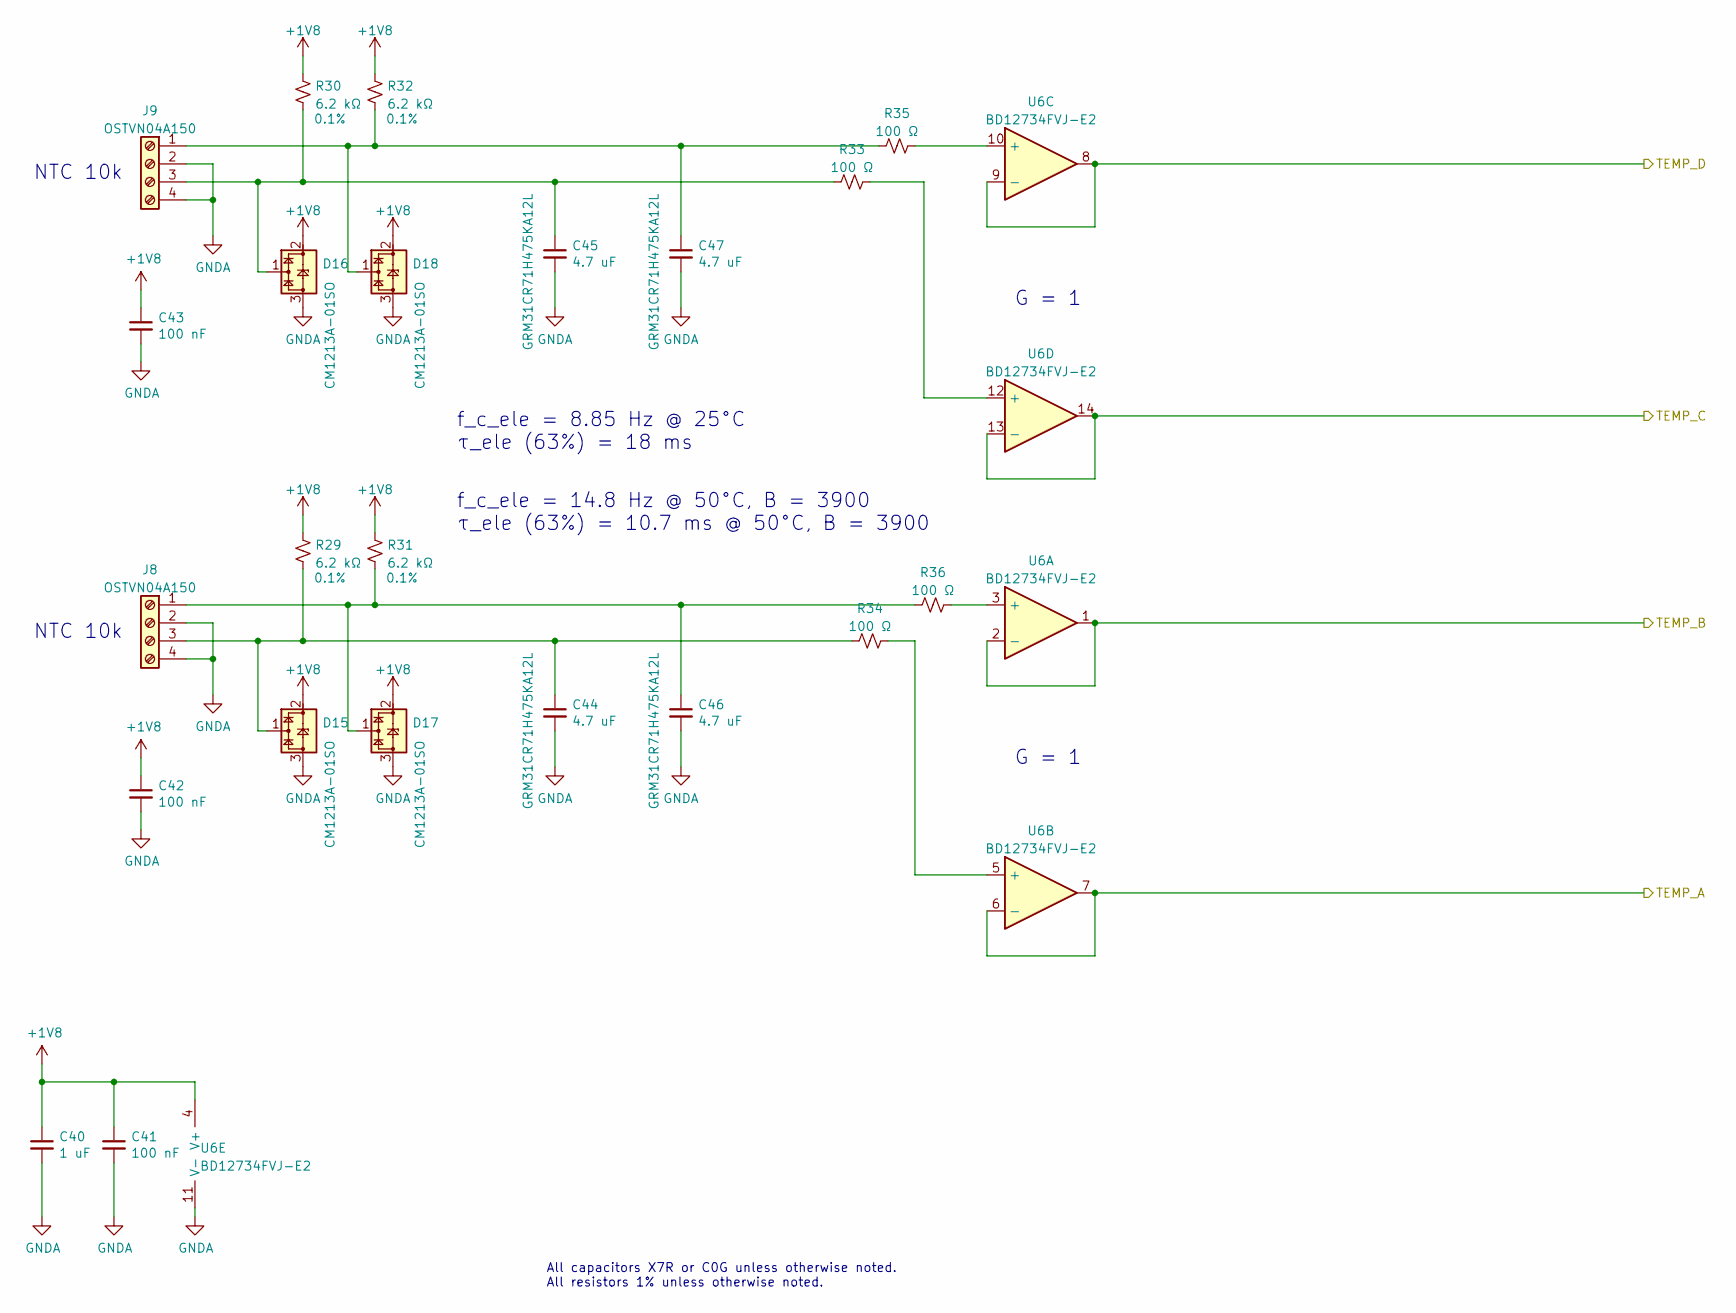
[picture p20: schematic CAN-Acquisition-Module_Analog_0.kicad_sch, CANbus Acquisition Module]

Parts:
C40: 1 uF; C_0603_1608Metric; Rated Voltage 25V; LCSC P/N C386079
C41, C42, C43: 100 nF; C_0402_1005Metric; Rated Voltage 16V; LCSC P/N C77014
C44, C45, C46, C47: 4.7 uF; C_1206_3216Metric; Rated Voltage 50V; LCSC P/N C92853
D15, D16, D17, D18: CM1213A-01SO; SOT-23; LCSC P/N C558429
J8, J9: OSTVN04A150; LCSC P/N C708735
R29, R30, R31, R32: 6.2 kΩ; R_0805_2012Metric; Tolerance 0.1%; LCSC P/N C351551
R33, R34, R35, R36: 100 Ω; R_0603_1608Metric; Tolerance 1%; LCSC P/N C105588
U6: BD12734FVJ-E2; TSSOP-14_4.4x5mm_P0.65mm; LCSC P/N C693071

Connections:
+1V8: C40.1, C41.1, C42.1, C43.1, D15.2 (VP), D16.2 (VP), D17.2 (VP), D18.2 (VP), R29.1, R30.1, R31.1, R32.1, U6.4 (V+); also elsewhere on the board
/ADC0: U6.6 (-), U6.7; also elsewhere on the board
/ADC1: U6.1, U6.2 (-); also elsewhere on the board
/ADC2: U6.13 (-), U6.14; also elsewhere on the board
/ADC3: U6.8, U6.9 (-); also elsewhere on the board
GNDA: C40.2, C41.2, C42.2, C43.2, C44.2, C45.2, C46.2, C47.2, D15.3 (VN), D16.3 (VN), D17.3 (VN), D18.3 (VN), J8.2, J8.4, J9.2, J9.4, U6.11 (V-); also elsewhere on the board
unnamed: C44.1, D15.1 (CH1), J8.3, R29.2, R34.2
unnamed: C45.1, D16.1 (CH1), J9.3, R30.2, R33.2
unnamed: C46.1, D17.1 (CH1), J8.1, R31.2, R36.2
unnamed: C47.1, D18.1 (CH1), J9.1, R32.2, R35.2
unnamed: R33.1, U6.12 (+)
unnamed: R34.1, U6.5 (+)
unnamed: R35.1, U6.10 (+)
unnamed: R36.1, U6.3 (+)

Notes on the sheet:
NTC 10k
All capacitors X7R or C0G unless otherwise noted. All resistors 1% unless otherwise noted.
f_c_ele = 14.8 Hz @ 50°C, B = 3900 τ_ele (63%) = 10.7 ms @ 50°C, B = 3900
G = 1
f_c_ele = 8.85 Hz @ 25°C τ_ele (63%) = 18 ms

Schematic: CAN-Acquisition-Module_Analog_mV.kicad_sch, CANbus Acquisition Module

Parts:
C51, C55, C56, C57, C58: 1 uF; C_0603_1608Metric; Rated Voltage 25V; LCSC P/N C386079
C52, C53, C54: 100 nF; C_0402_1005Metric; Rated Voltage 16V; LCSC P/N C77014
D21, D22, D23, D24: CM1213A-01SO; SOT-23; LCSC P/N C558429
J10, J11: OSTVN04A150; LCSC P/N C708735
R52, R53, R54, R55: 10 kΩ; R_0603_1608Metric; Tolerance 1%; LCSC P/N C98220
R56, R57, R58, R59: Ω; R_0603_1608Metric; LCSC P/N DNP
R60, R61, R62, R63: 1 kΩ; R_0603_1608Metric; Tolerance 1%; LCSC P/N C22548
R64, R65, R66, R67: 2 kΩ; R_0603_1608Metric; Tolerance 1%; LCSC P/N C22975
R68, R69, R70, R71: 47 kΩ; R_0603_1608Metric; Tolerance 1%; LCSC P/N C105579
U9: OPA4317IPWR; TSSOP-14_4.4x5mm_P0.65mm; LCSC P/N C783605

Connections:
+1V8: C51.1, C52.1, C53.1, C54.1, D21.2 (VP), D22.2 (VP), D23.2 (VP), D24.2 (VP), U9.4 (V+); also elsewhere on the board
/ADC8: R68.2, U9.7; also elsewhere on the board
/ADC9: R71.2, U9.1; also elsewhere on the board
/ADC10: R70.2, U9.14; also elsewhere on the board
/ADC11: R69.2, U9.8; also elsewhere on the board
GNDA: C51.2, C52.2, C53.2, C54.2, C55.2, C56.2, C57.2, C58.2, D21.3 (VN), D22.3 (VN), D23.3 (VN), D24.3 (VN), J10.2, J10.4, J11.2, J11.4, R56.2, R57.2, R58.2, R59.2, R60.1, R61.1, R62.1, R63.1, U9.11 (V-); also elsewhere on the board
unnamed: C55.1, R53.2, R56.1, U9.5 (+)
unnamed: C56.1, R55.2, R57.1, U9.12 (+)
unnamed: C57.1, R52.2, R58.1, U9.3 (+)
unnamed: C58.1, R54.2, R59.1, U9.10 (+)
unnamed: D21.1 (CH1), J10.3, R53.1
unnamed: D22.1 (CH1), J11.3, R55.1
unnamed: D23.1 (CH1), J10.1, R52.1
unnamed: D24.1 (CH1), J11.1, R54.1
unnamed: R60.2, R64.1, U9.2 (-)
unnamed: R61.2, R65.1, U9.6 (-)
unnamed: R62.2, R66.1, U9.9 (-)
unnamed: R63.2, R67.1, U9.13 (-)
unnamed: R64.2, R71.1
unnamed: R65.2, R68.1
unnamed: R66.2, R69.1
unnamed: R67.2, R70.1

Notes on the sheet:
All capacitors X7R or C0G unless otherwise noted. All resistors 1% unless otherwise noted.
Other good cheap zero-drift op-amp: NCS21874/NCV21874
0-36 mV
G = 50
fc_ele = 15.9 Hz τ_ele (63%) = 10 ms

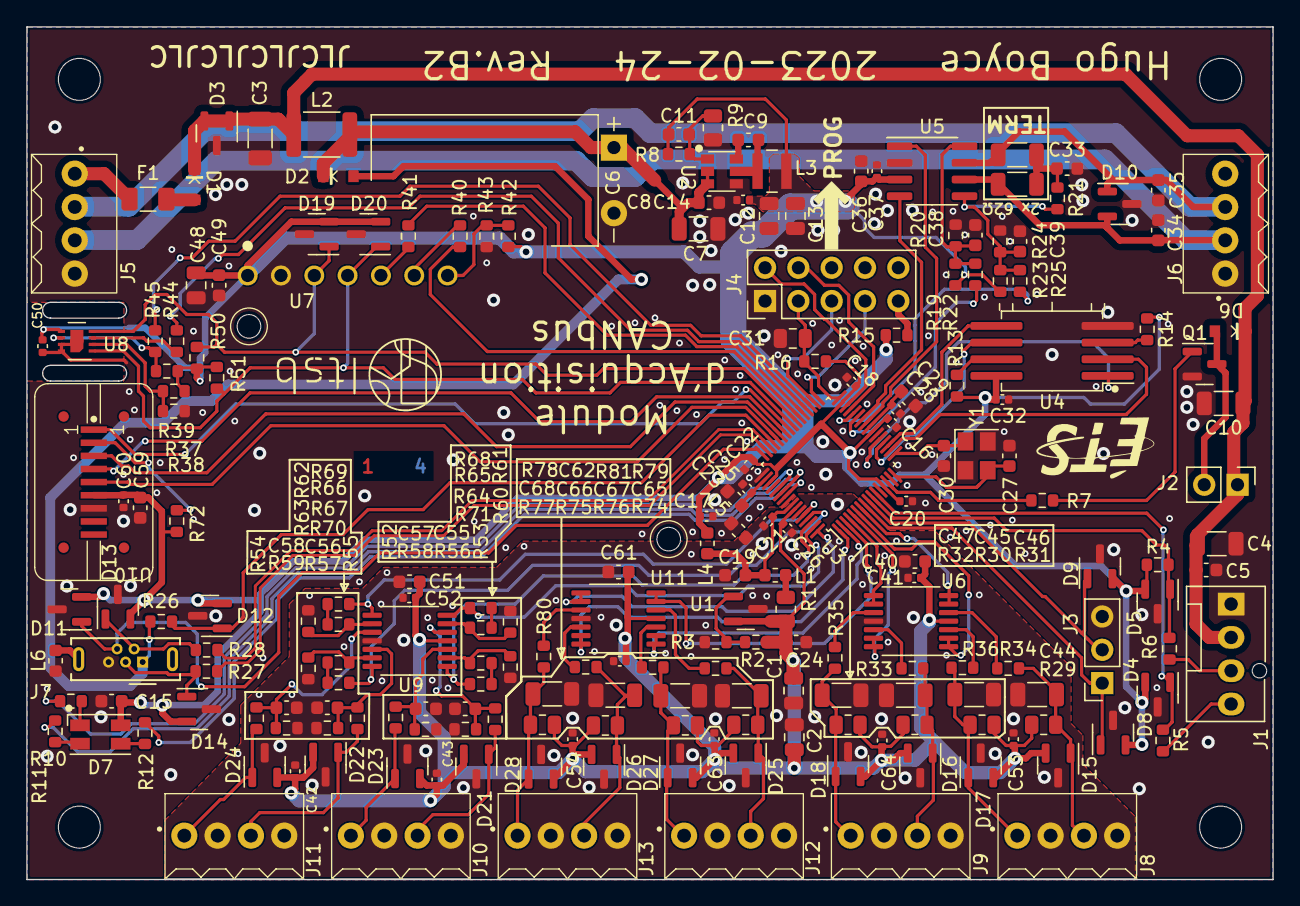
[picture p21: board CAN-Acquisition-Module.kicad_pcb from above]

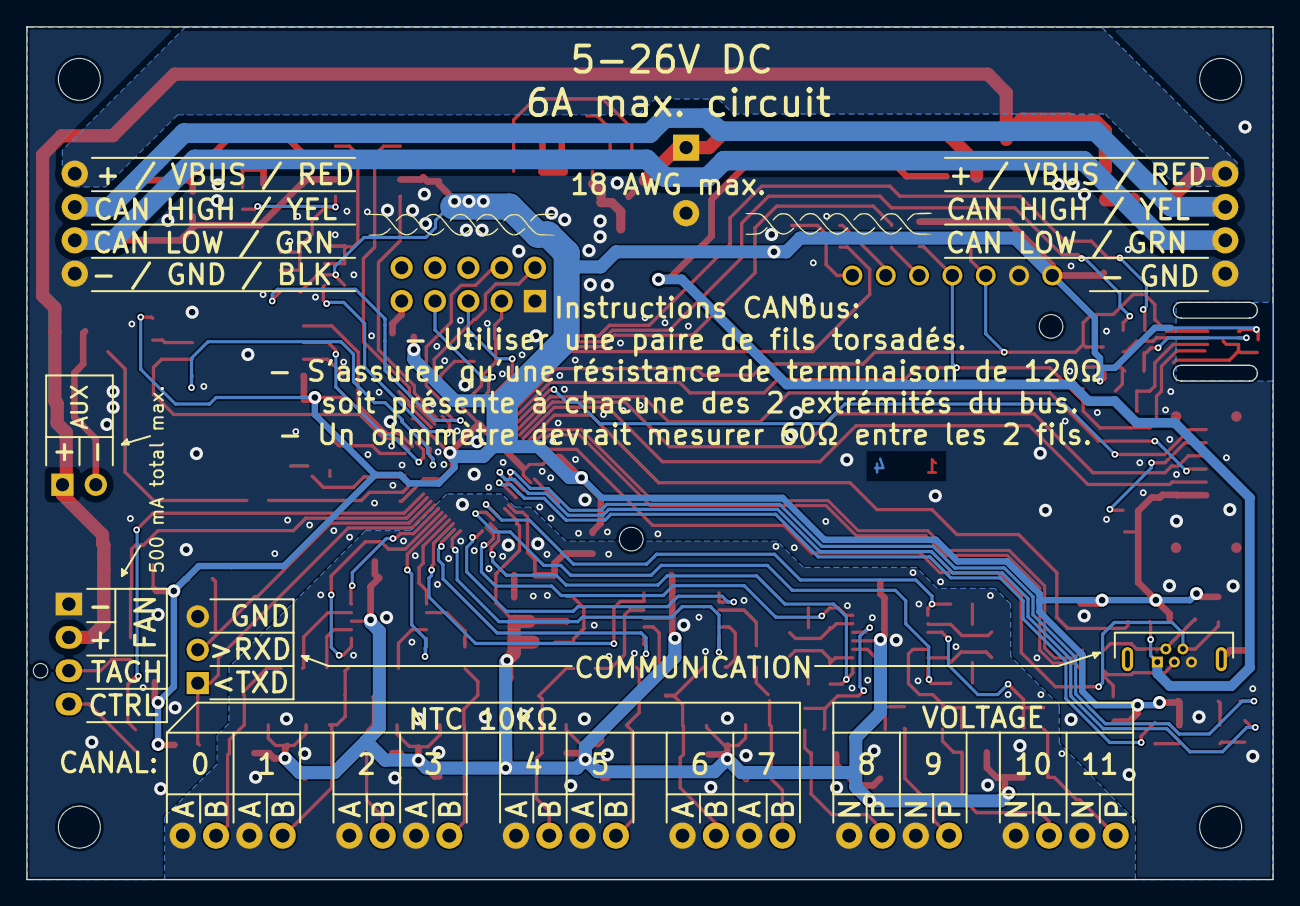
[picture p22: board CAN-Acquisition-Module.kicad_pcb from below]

Board: 4 copper layers, 95.0 x 65.0 mm, 214 parts (2 on the bottom side), 124 nets.

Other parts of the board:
C61: 1 uF; C_0603_1608Metric
C62, C63, C64: 100 nF; C_0402_1005Metric
C65, C66, C67, C68: 4.7 uF; C_1206_3216Metric
D25, D26, D27, D28: CM1213A-01SO; SOT-23
G1, G2, G5, G5#2: LOGO
J12, J13: OSTVN04A150
R74, R75, R76, R77: 6.2 kΩ; R_0805_2012Metric
R78, R79, R80, R81: 100 Ω; R_0603_1608Metric
U11: BD12734FVJ-E2; TSSOP-14_4.4x5mm_P0.65mm

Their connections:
+1V8: C61.1, C62.1, C63.1, C64.1, D25.2 (VP), D26.2 (VP), D27.2 (VP), D28.2 (VP), R74.1, R75.1, R76.1, R77.1, U11.4 (V+); also elsewhere on the board
/ADC4: U11.6 (-), U11.7; also elsewhere on the board
/ADC5: U11.1, U11.2 (-); also elsewhere on the board
/ADC6: U11.13 (-), U11.14; also elsewhere on the board
/ADC7: U11.8, U11.9 (-); also elsewhere on the board
GNDA: C61.2, C62.2, C63.2, C64.2, C65.2, C66.2, C67.2, C68.2, D25.3 (VN), D26.3 (VN), D27.3 (VN), D28.3 (VN), J12.2, J12.4, J13.2, J13.4, U11.11 (V-); also elsewhere on the board
unnamed: C65.1, D25.1 (CH1), J12.3, R74.2, R79.2
unnamed: C66.1, D26.1 (CH1), J13.3, R75.2, R78.2
unnamed: C67.1, D27.1 (CH1), J12.1, R76.2, R81.2
unnamed: C68.1, D28.1 (CH1), J13.1, R77.2, R80.2
unnamed: R78.1, U11.12 (+)
unnamed: R79.1, U11.5 (+)
unnamed: R80.1, U11.10 (+)
unnamed: R81.1, U11.3 (+)

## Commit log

2022-05-26 Initial files added
    [CAN-Acquisition-Module.kicad_pcb, CAN-Acquisition-Module.sch, CAN-Acquisition-Module_MCU.sch]
2022-05-26 Schematic started
    MCU section well advanced, power section started as well
    [CAN-Acquisition-Module.kicad_sch, CAN-Acquisition-Module_MCU.kicad_sch, CAN-Acquisition-Module_MCU.sch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]
2022-05-26 Added CAN page
    also power section has advanced
    [CAN-Acquisition-Module.kicad_sch, CAN-Acquisition-Module_CANbus.kicad_sch, CAN-Acquisition-Module_MCU.kicad_sch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]
2022-05-27 Mid-day backup
    [CAN-Acquisition-Module.kicad_sch, CAN-Acquisition-Module_CANbus.kicad_sch, CAN-Acquisition-Module_MCU.kicad_sch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]
2022-05-27 Advanced CAN section and "finished" power section
    [CAN-Acquisition-Module.kicad_sch, CAN-Acquisition-Module_CANbus.kicad_sch, CAN-Acquisition-Module_MCU.kicad_sch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]
2022-05-30 Finished CAN section
    [CAN-Acquisition-Module.kicad_sch, CAN-Acquisition-Module_CANbus.kicad_sch, CAN-Acquisition-Module_MCU.kicad_sch]
2022-05-31 Added stuff and cleanup
    Added LED, Power outputs, additional descriptions
    [CAN-Acquisition-Module.kicad_sch, CAN-Acquisition-Module_CANbus.kicad_sch, CAN-Acquisition-Module_LED.kicad_sch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]
2022-05-31 Added empty sheets
    [CAN-Acquisition-Module.kicad_sch, CAN-Acquisition-Module_Analog.kicad_sch, CAN-Acquisition-Module_Screen.kicad_sch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]
2022-06-01 Added analog and sensors sections
    [CAN-Acquisition-Module.kicad_sch, CAN-Acquisition-Module_Analog_0.kicad_sch, CAN-Acquisition-Module_Analog_mV.kicad_sch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]
2022-06-02 Added screen sections and annotations
    [CAN-Acquisition-Module.kicad_sch, CAN-Acquisition-Module_Analog_0.kicad_sch, CAN-Acquisition-Module_Analog_mV.kicad_sch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]
2022-06-03 PCB started
    Placement well advanced
    [CAN-Acquisition-Module.kicad_pcb, CAN-Acquisition-Module.kicad_sch, CAN-Acquisition-Module_Analog_0.kicad_sch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]
2022-06-07 Added board settings
    [CAN-Acquisition-Module.kicad_pcb]
2022-06-07 Layout of analog section started
    [CAN-Acquisition-Module.kicad_pcb, CAN-Acquisition-Module.kicad_sch, CAN-Acquisition-Module_Analog_0.kicad_sch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]
2022-06-09 Analog section, screen and USB finished
    [CAN-Acquisition-Module.kicad_pcb, CAN-Acquisition-Module.kicad_sch, CAN-Acquisition-Module_Analog_mV.kicad_sch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]
2022-06-10 Finished power outputs
    [CAN-Acquisition-Module.kicad_pcb, CAN-Acquisition-Module.kicad_sch, CAN-Acquisition-Module_Analog_0.kicad_sch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]
2022-06-13 Only CAN transceiver left
    SPi flash should be added too
    [CAN-Acquisition-Module.kicad_pcb, CAN-Acquisition-Module.kicad_sch, CAN-Acquisition-Module_Power.kicad_sch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]
2022-06-13 forgor to save
    [CAN-Acquisition-Module.kicad_sch, CAN-Acquisition-Module_Analog_0.kicad_sch, CAN-Acquisition-Module_Analog_mV.kicad_sch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]
2022-06-15 Rev. A1 release
    [CAN-Acquisition-Module-B_Cu.gbr, CAN-Acquisition-Module-B_Mask.gbr, CAN-Acquisition-Module-B_Paste.gbr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]
2022-06-16 Added as-ordered P/Ns and regenerated Gerbers
    [CAN-Acquisition-Module-B_Cu.gbr, CAN-Acquisition-Module-B_Mask.gbr, CAN-Acquisition-Module-B_Paste.gbr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]
2022-06-30 Rev. A2
    U1 had wrong pinout. NT1 label removed from silk. Green LED resistor increased in value
    [CAN-Acquisition-Module.kicad_pcb, CAN-Acquisition-Module.kicad_sch, CAN-Acquisition-Module_MCU.kicad_sch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]
2022-07-05 Changed the node where the V_USB diode connects.
    Having the V_USB go through the VBUS inductor caused the voltage to sag too low.
    [CAN-Acquisition-Module.kicad_pcb, CAN-Acquisition-Module_Power.kicad_sch]
2022-07-14 Rev. A2 started
    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
    [CAN-Acquisition-Module.kicad_pcb, CAN-Acquisition-Module.kicad_sch, CAN-Acquisition-Module_MCU.kicad_sch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]
2022-07-14 Added TODO
    Route V_USB to C6, reduce screw terminal hole size, thermally isolate SHT3x sensor
    [CAN-Acquisition-Module.kicad_pcb]
2022-07-28 Rev.A2 pretty much finished
    V USB bypasses inductor L2
    Srew terminal pin holes size reduced
    Thermally isolated SHT3x
    Fixed U1 footprint
    [CAN-Acquisition-Module.kicad_pcb, CAN-Acquisition-Module.kicad_sch, CAN-Acqusition-Module_Screen.kicad_sch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]
2022-07-28 Did not stage pcb during last commit. Oops!
    [CAN-Acquisition-Module.kicad_pcb]
2022-09-20 changed the date on the board for release A2
    [CAN-Acquisition-Module.kicad_pcb]
2022-09-20 Exported all files for A2 release
    [CAN-Acquisition-Module-B_Cu.gbr, CAN-Acquisition-Module-B_Mask.gbr, CAN-Acquisition-Module-B_Paste.gbr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]
2022-10-04 Fixed board and re-exported Gerbers. BOM is a WIP
    Some design rules were violated
    [CAN-Acquisition-Module-B_Cu.gbr, CAN-Acquisition-Module-B_Mask.gbr, CAN-Acquisition-Module-B_Paste.gbr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]
2022-10-04 BOM updated for LCSC. Still a WIP.
    [CAN-Acquisition-Module_Analog_0.kicad_sch, CAN-Acquisition-Module_Analog_mV.kicad_sch, CAN-Acquisition-Module_CANbus.kicad_sch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]
2022-10-04 BOM updated for LCSC. Still a WIP
    [CAN-Acquisition-Module_Analog_0.kicad_sch, CAN-Acquisition-Module_Analog_mV.kicad_sch, CAN-Acquisition-Module_CANbus.kicad_sch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]
2022-10-05 Changed 47uF cap to 4.7uF
    Filtration can be done in software instead of hardware
    [CAN-Acquisition-Module.kicad_sch, CAN-Acquisition-Module_Analog_0.kicad_sch]
2022-10-06 Added differential BOM for order (to be removed later)
    [CAN-Acquisition-Module.kicad_sch, CAN-Acquisition-Module_BOM_DIFF_2022-10-05.ods, CAN-Acquisition-Module_CANbus.kicad_sch]
2022-10-18 Added BOM diff for extra order
    [CAN-Acquisition-Module_BOM_DIFF_2022-10-05.ods]
2022-10-19 Created Rev B1
    Replaced buck regulator S-8581AA with AP63200 because of shortage
    [CAN-Acquisition-Module-B_Cu.gbr, CAN-Acquisition-Module-B_Mask.gbr, CAN-Acquisition-Module-B_Paste.gbr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]
2022-10-24 Exported pdfs and updated cartouche
    [CAN-Acquisition-Module.kicad_sch]
2023-02-03 Created rev B2 to fix low pass filter specs
    [CAN-Acquisition-Module.kicad_sch, CAN-Acquisition-Module_Analog_0.kicad_sch]
2023-02-03 Forgot to change project file
    [CAN-Acquisition-Module.kicad_sch, CAN-Acquisition-Module_Analog_0.kicad_sch, CAN-Acquisition-Module_Analog_mV.kicad_sch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]
2023-02-25 Corrected U1 in schematic
    [CAN-Acquisition-Module.kicad_pcb, CAN-Acquisition-Module.kicad_sch, CAN-Acquisition-Module_Analog_0.kicad_sch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]
2023-03-10 Improved ground trace width
    [CAN-Acquisition-Module.kicad_pcb]
